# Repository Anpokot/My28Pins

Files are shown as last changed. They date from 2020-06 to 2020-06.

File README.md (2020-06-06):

## My28Pins Project

### My28Pins is an a microcontroller board based on Arduino Uno<br />
The main difference from Uno is an improved layout and selection of 5V or 3.3V operation voltage<br />
This repository contains Altium design files and fabrication output files

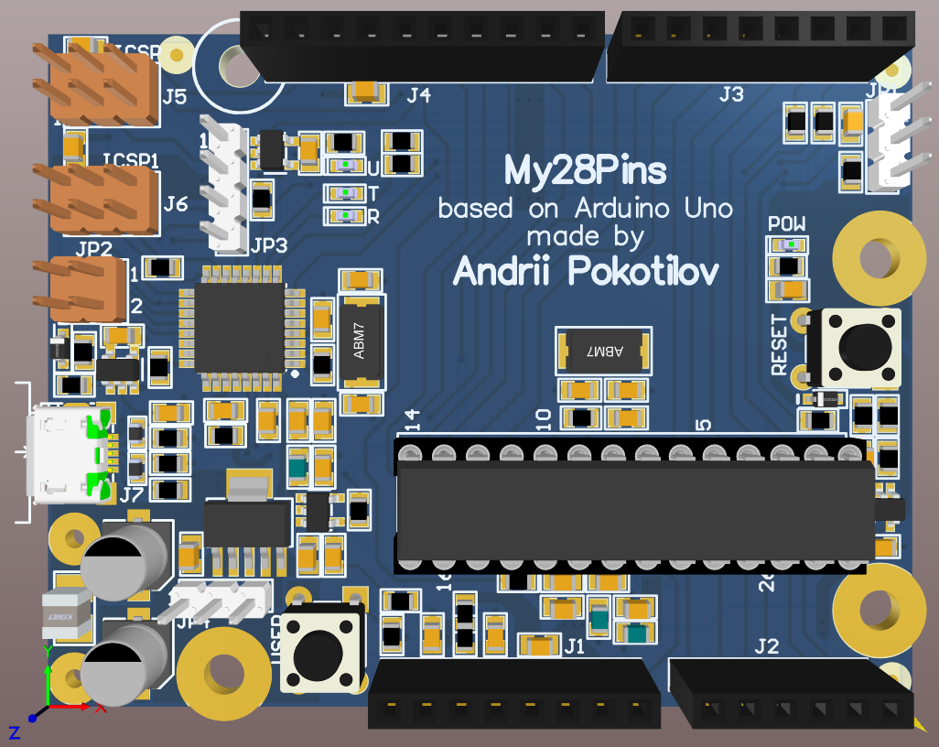
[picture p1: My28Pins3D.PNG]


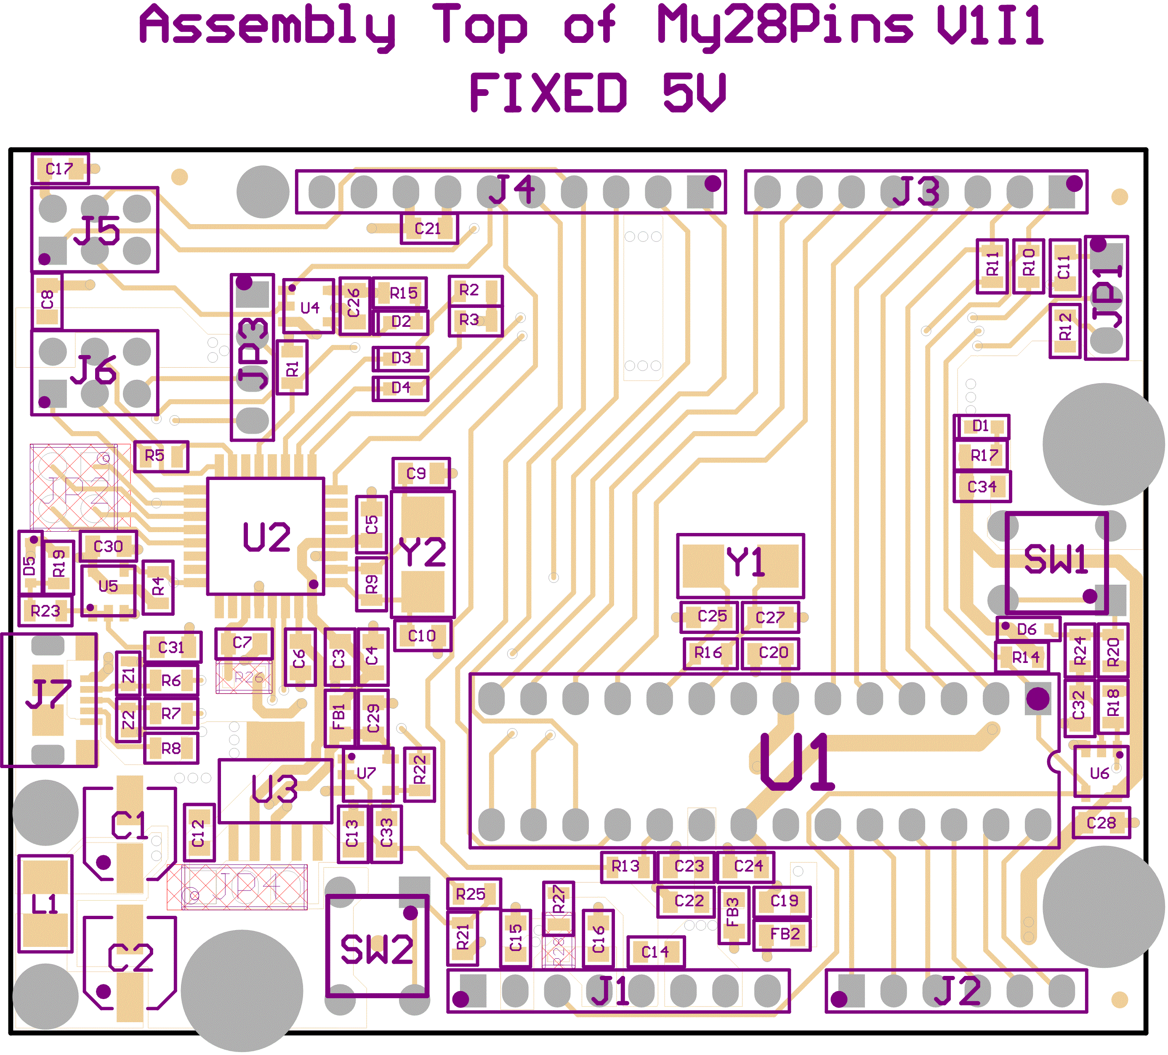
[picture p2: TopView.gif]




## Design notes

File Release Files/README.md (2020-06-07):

### Folder Sructure

Output Job file configured to automaticaly create folder structure

Specify your release folder and template then folow each step:
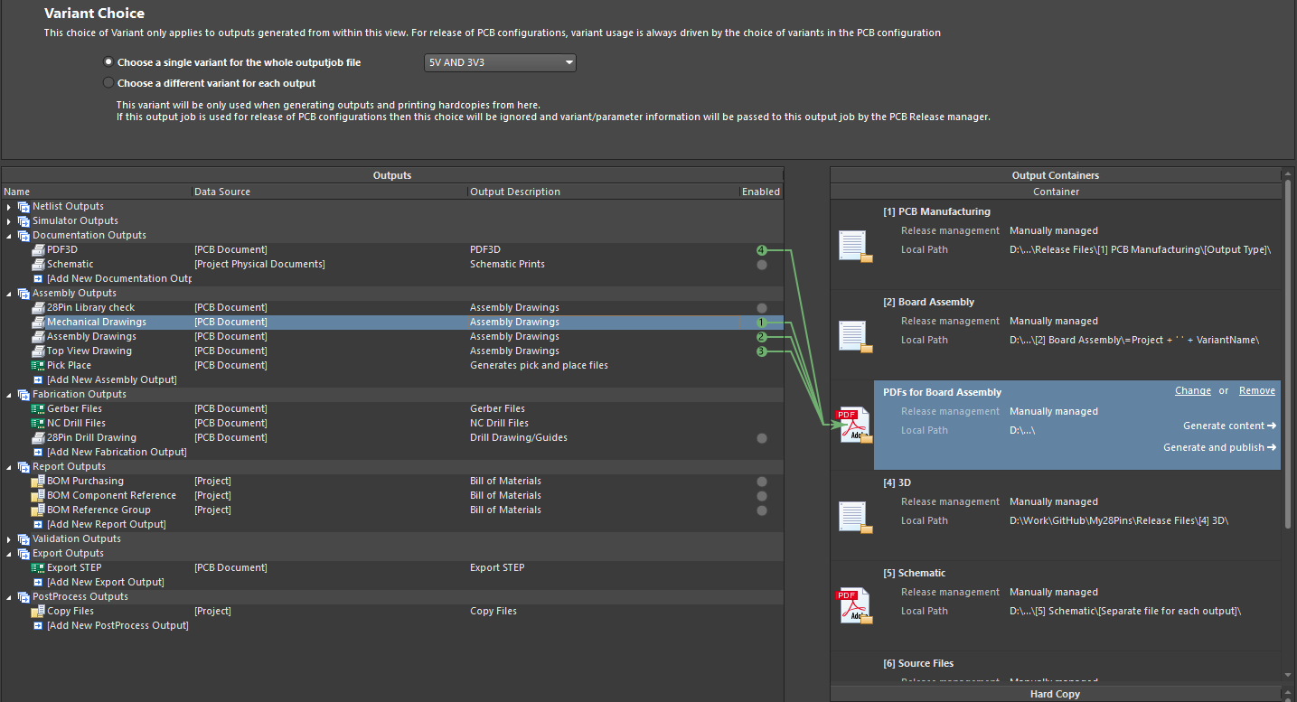
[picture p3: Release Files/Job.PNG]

Each Variant have its own folder

Resulting folder structure should be like this:
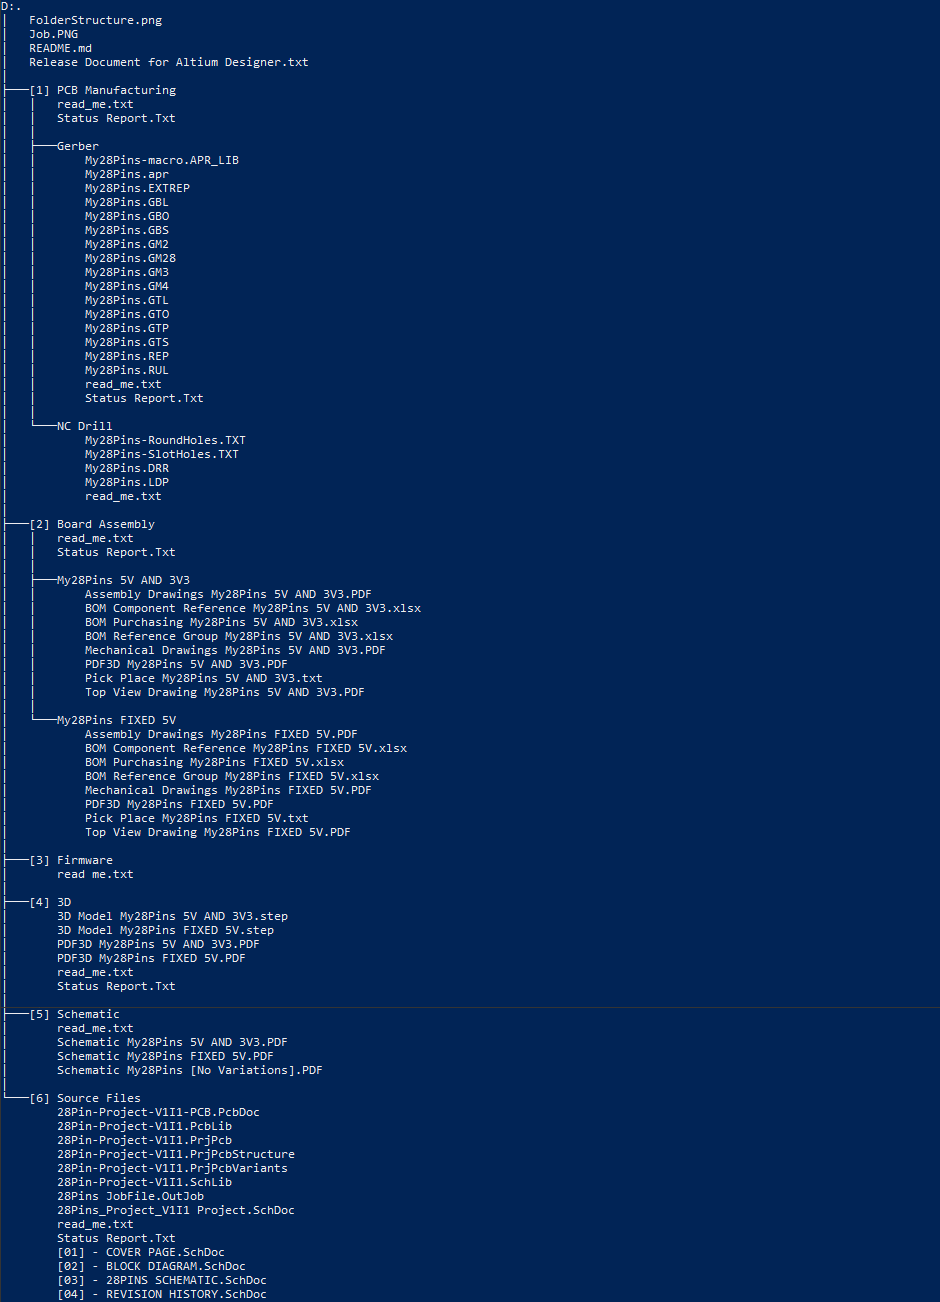
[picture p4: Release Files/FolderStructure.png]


### NOTE: Your variant name must not contain windows prohibited symbols:
`<` `>` `:` `"` `/` `\` `|` `?` `*`

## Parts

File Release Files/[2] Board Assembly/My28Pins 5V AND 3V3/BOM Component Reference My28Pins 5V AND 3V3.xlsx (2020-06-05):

 | Component reference list |  |  | BOM Component Reference
 |  | Source Data From: | 28Pin-Project-V1I1.PrjPcb |  | Contact: |  | Generated by:
 |  | Project: | My28Pins |  |  |  | Andrii Pokotilov
 |  | Variant: | 5V AND 3V3
 | Report Date: | 6/5/2020 | 11:48 AM |  |  |  | https://github.com/Anpokot
 | Print Date: | 2020-06-05 | 11:48:37
# | Designator | Comment | Description | Manufacturer 1 | Manufacturer Part Number 1 | Case/Package | Supplier 1 | Supplier Part Number 1
1 | C1 | 100uF/10V | Cap Aluminum 100uF 10V 20% (5 X 5.4mm) SMD 50mA 1000 hr 85°C T/R | Panasonic | EEE-1AA101WR | Radial | Digi-Key | PCE3867CT-ND
2 | C2 | 100uF/10V | Cap Aluminum 100uF 10V 20% (5 X 5.4mm) SMD 50mA 1000 hr 85°C T/R | Panasonic | EEE-1AA101WR | Radial | Digi-Key | PCE3867CT-ND
3 | C3 | 100n | TDK - C2012X7R1H104K085AA - SMD Multilayer Ceramic Capacitor, 0.1 µF, 50 V, 0805 [2012 Metric], ± 10%, X7R, C Series | TDK | C2012X7R1H104K085AA | 0805 | Digi-Key | 445-7534-1-ND
4 | C4 | 10uF/16V | CERAMIC CAPACITOR, 10UF, 16V, X5R, 20%, 0805, FULL REEL; Product Range:C Series; Capacitance:10 F; Capacitance Tolerance: 20%; Dielectric Characteristic:X5R; Voltage Rating:16V; Ceramic Capacitor Case:0805 [2012 Metric]; MSL:- ;RoHS Compliant: Yes | TDK | C2012X5R1C106M125AC | 0805 | Farnell | 2525134
5 | C5 | 100n | TDK - C2012X7R1H104K085AA - SMD Multilayer Ceramic Capacitor, 0.1 µF, 50 V, 0805 [2012 Metric], ± 10%, X7R, C Series | TDK | C2012X7R1H104K085AA | 0805 | Digi-Key | 445-7534-1-ND
6 | C6 | 100n | TDK - C2012X7R1H104K085AA - SMD Multilayer Ceramic Capacitor, 0.1 µF, 50 V, 0805 [2012 Metric], ± 10%, X7R, C Series | TDK | C2012X7R1H104K085AA | 0805 | Digi-Key | 445-7534-1-ND
7 | C7 | 1uF/25V | TDK - C2012X5R1E105K125AA - SMD Multilayer Ceramic Capacitor, 1 µF, 25 V, 0805 [2012 Metric], ± 10%, X5R, C Series | TDK | C2012X5R1E105K125AA | 0805 | Digi-Key | 445-1419-1-ND
8 | C8 | 100n | TDK - C2012X7R1H104K085AA - SMD Multilayer Ceramic Capacitor, 0.1 µF, 50 V, 0805 [2012 Metric], ± 10%, X7R, C Series | TDK | C2012X7R1H104K085AA | 0805 | Digi-Key | 445-7534-1-ND
9 | C9 | 18p | CAP CER 18PF 50V C0G/NP0 0805 | KEMET | C0805C180J5GACTU | 0805 | Digi-Key | 399-1112-1-ND
10 | C10 | 18p | CAP CER 18PF 50V C0G/NP0 0805 | KEMET | C0805C180J5GACTU | 0805 | Digi-Key | 399-1112-1-ND
11 | C11 | 100n | TDK - C2012X7R1H104K085AA - SMD Multilayer Ceramic Capacitor, 0.1 µF, 50 V, 0805 [2012 Metric], ± 10%, X7R, C Series | TDK | C2012X7R1H104K085AA | 0805 | Digi-Key | 445-7534-1-ND
12 | C12 | 10uF/16V | CERAMIC CAPACITOR, 10UF, 16V, X5R, 20%, 0805, FULL REEL; Product Range:C Series; Capacitance:10 F; Capacitance Tolerance: 20%; Dielectric Characteristic:X5R; Voltage Rating:16V; Ceramic Capacitor Case:0805 [2012 Metric]; MSL:- ;RoHS Compliant: Yes | TDK | C2012X5R1C106M125AC | 0805 | Farnell | 2525134
13 | C13 | 10uF/16V | CERAMIC CAPACITOR, 10UF, 16V, X5R, 20%, 0805, FULL REEL; Product Range:C Series; Capacitance:10 F; Capacitance Tolerance: 20%; Dielectric Characteristic:X5R; Voltage Rating:16V; Ceramic Capacitor Case:0805 [2012 Metric]; MSL:- ;RoHS Compliant: Yes | TDK | C2012X5R1C106M125AC | 0805 | Farnell | 2525134
14 | C14 | 100n | TDK - C2012X7R1H104K085AA - SMD Multilayer Ceramic Capacitor, 0.1 µF, 50 V, 0805 [2012 Metric], ± 10%, X7R, C Series | TDK | C2012X7R1H104K085AA | 0805 | Digi-Key | 445-7534-1-ND
15 | C15 | 100n | TDK - C2012X7R1H104K085AA - SMD Multilayer Ceramic Capacitor, 0.1 µF, 50 V, 0805 [2012 Metric], ± 10%, X7R, C Series | TDK | C2012X7R1H104K085AA | 0805 | Digi-Key | 445-7534-1-ND
16 | C16 | 100n | TDK - C2012X7R1H104K085AA - SMD Multilayer Ceramic Capacitor, 0.1 µF, 50 V, 0805 [2012 Metric], ± 10%, X7R, C Series | TDK | C2012X7R1H104K085AA | 0805 | Digi-Key | 445-7534-1-ND
17 | C17 | 100n | TDK - C2012X7R1H104K085AA - SMD Multilayer Ceramic Capacitor, 0.1 µF, 50 V, 0805 [2012 Metric], ± 10%, X7R, C Series | TDK | C2012X7R1H104K085AA | 0805 | Digi-Key | 445-7534-1-ND
18 | C19 | 10uF/16V | CERAMIC CAPACITOR, 10UF, 16V, X5R, 20%, 0805, FULL REEL; Product Range:C Series; Capacitance:10 F; Capacitance Tolerance: 20%; Dielectric Characteristic:X5R; Voltage Rating:16V; Ceramic Capacitor Case:0805 [2012 Metric]; MSL:- ;RoHS Compliant: Yes | TDK | C2012X5R1C106M125AC | 0805 | Farnell | 2525134
19 | C20 | 100n | TDK - C2012X7R1H104K085AA - SMD Multilayer Ceramic Capacitor, 0.1 µF, 50 V, 0805 [2012 Metric], ± 10%, X7R, C Series | TDK | C2012X7R1H104K085AA | 0805 | Digi-Key | 445-7534-1-ND
20 | C21 | 10uF/16V | CERAMIC CAPACITOR, 10UF, 16V, X5R, 20%, 0805, FULL REEL; Product Range:C Series; Capacitance:10 F; Capacitance Tolerance: 20%; Dielectric Characteristic:X5R; Voltage Rating:16V; Ceramic Capacitor Case:0805 [2012 Metric]; MSL:- ;RoHS Compliant: Yes | TDK | C2012X5R1C106M125AC | 0805 | Farnell | 2525134
21 | C22 | 10uF/16V | CERAMIC CAPACITOR, 10UF, 16V, X5R, 20%, 0805, FULL REEL; Product Range:C Series; Capacitance:10 F; Capacitance Tolerance: 20%; Dielectric Characteristic:X5R; Voltage Rating:16V; Ceramic Capacitor Case:0805 [2012 Metric]; MSL:- ;RoHS Compliant: Yes | TDK | C2012X5R1C106M125AC | 0805 | Farnell | 2525134
22 | C23 | 100n | TDK - C2012X7R1H104K085AA - SMD Multilayer Ceramic Capacitor, 0.1 µF, 50 V, 0805 [2012 Metric], ± 10%, X7R, C Series | TDK | C2012X7R1H104K085AA | 0805 | Digi-Key | 445-7534-1-ND
23 | C24 | 100n | TDK - C2012X7R1H104K085AA - SMD Multilayer Ceramic Capacitor, 0.1 µF, 50 V, 0805 [2012 Metric], ± 10%, X7R, C Series | TDK | C2012X7R1H104K085AA | 0805 | Digi-Key | 445-7534-1-ND
24 | C25 | 18p | CAP CER 18PF 50V C0G/NP0 0805 | KEMET | C0805C180J5GACTU | 0805 | Digi-Key | 399-1112-1-ND
25 | C26 | 100n | TDK - C2012X7R1H104K085AA - SMD Multilayer Ceramic Capacitor, 0.1 µF, 50 V, 0805 [2012 Metric], ± 10%, X7R, C Series | TDK | C2012X7R1H104K085AA | 0805 | Digi-Key | 445-7534-1-ND
26 | C27 | 18p | CAP CER 18PF 50V C0G/NP0 0805 | KEMET | C0805C180J5GACTU | 0805 | Digi-Key | 399-1112-1-ND
27 | C28 | 100n | TDK - C2012X7R1H104K085AA - SMD Multilayer Ceramic Capacitor, 0.1 µF, 50 V, 0805 [2012 Metric], ± 10%, X7R, C Series | TDK | C2012X7R1H104K085AA | 0805 | Digi-Key | 445-7534-1-ND
28 | C29 | 100n | TDK - C2012X7R1H104K085AA - SMD Multilayer Ceramic Capacitor, 0.1 µF, 50 V, 0805 [2012 Metric], ± 10%, X7R, C Series | TDK | C2012X7R1H104K085AA | 0805 | Digi-Key | 445-7534-1-ND
29 | C30 | 100n | TDK - C2012X7R1H104K085AA - SMD Multilayer Ceramic Capacitor, 0.1 µF, 50 V, 0805 [2012 Metric], ± 10%, X7R, C Series | TDK | C2012X7R1H104K085AA | 0805 | Digi-Key | 445-7534-1-ND
30 | C31 | 100n | TDK - C2012X7R1H104K085AA - SMD Multilayer Ceramic Capacitor, 0.1 µF, 50 V, 0805 [2012 Metric], ± 10%, X7R, C Series | TDK | C2012X7R1H104K085AA | 0805 | Digi-Key | 445-7534-1-ND
31 | C32 | 100n | TDK - C2012X7R1H104K085AA - SMD Multilayer Ceramic Capacitor, 0.1 µF, 50 V, 0805 [2012 Metric], ± 10%, X7R, C Series | TDK | C2012X7R1H104K085AA | 0805 | Digi-Key | 445-7534-1-ND
32 | C33 | 100n | TDK - C2012X7R1H104K085AA - SMD Multilayer Ceramic Capacitor, 0.1 µF, 50 V, 0805 [2012 Metric], ± 10%, X7R, C Series | TDK | C2012X7R1H104K085AA | 0805 | Digi-Key | 445-7534-1-ND
33 | C34 | 10uF/16V | CERAMIC CAPACITOR, 10UF, 16V, X5R, 20%, 0805, FULL REEL; Product Range:C Series; Capacitance:10 F; Capacitance Tolerance: 20%; Dielectric Characteristic:X5R; Voltage Rating:16V; Ceramic Capacitor Case:0805 [2012 Metric]; MSL:- ;RoHS Compliant: Yes | TDK | C2012X5R1C106M125AC | 0805 | Farnell | 2525134
34 | D1 | GREEN | LED Uni-Color Green 572nm 2-Pin Chip 0603(1608Metric) T/R | Osram Opto | LGL29K-G2J1-24-Z | 0603 | Digi-Key | 475-2709-1-ND
35 | D2 | ORANGE | OSRAM - LO L29K-H2K1-24-Z - SMARTLED 0603 ORANGE | Osram Opto | LOL29K-H2K1-24-Z | 0603 | Digi-Key | 475-2740-1-ND
36 | D3 | ORANGE | OSRAM - LO L29K-H2K1-24-Z - SMARTLED 0603 ORANGE | Osram Opto | LOL29K-H2K1-24-Z | 0603 | Digi-Key | 475-2740-1-ND
37 | D4 | ORANGE | OSRAM - LO L29K-H2K1-24-Z - SMARTLED 0603 ORANGE | Osram Opto | LOL29K-H2K1-24-Z | 0603 | Digi-Key | 475-2740-1-ND
38 | D5 | BAT54HT1G | Small Signal Schottky Diode, Single, 30 V, 200 mA, 800 mV, 600 mA, 150 C ;RoHS Compliant: Yes | ON Semiconductor / Fairchild | BAT54HT1G |  | Digi-Key | BAT54HT1GOSCT-ND
39 | D6 | BAT54HT1G | Small Signal Schottky Diode, Single, 30 V, 200 mA, 800 mV, 600 mA, 150 C ;RoHS Compliant: Yes | ON Semiconductor / Fairchild | BAT54HT1G |  | Digi-Key | BAT54HT1GOSCT-ND
40 | FB1 | MPZ2012S601AT000 | FERRITE BEAD 600 OHM 0805 1LN | TDK | MPZ2012S601AT000 | 0805 | Digi-Key | 445-2206-1-ND
41 | FB2 | MPZ2012S601AT000 | FERRITE BEAD 600 OHM 0805 1LN | TDK | MPZ2012S601AT000 | 0805 | Digi-Key | 445-2206-1-ND
42 | FB3 | MPZ2012S601AT000 | FERRITE BEAD 600 OHM 0805 1LN | TDK | MPZ2012S601AT000 | 0805 | Digi-Key | 445-2206-1-ND
43 | J1 | Hdr 1x8 | 8POS, 2.54MM, 1ROW | Harwin | M20-7910842R |  | Digi-Key | 952-3200-1-ND
44 | J2 | Hdr 1x6 | 6Pin 2.54mm Conn Socket Strip SKT 6 POS 2.54mm Solder ST Thru-Hole Tube | Harwin | M20-7820642 | SIL | Digi-Key | 952-1808-ND
45 | J3 | Hdr 1x8 | 8POS, 2.54MM, 1ROW | Harwin | M20-7910842R |  | Digi-Key | 952-3200-1-ND
46 | J4 | Hdr 1x10 | 10Pin, 2.54 mm, Tin Plated Contacts | Harwin | M20-7821046 | SIL | Digi-Key | 952-1847-ND
47 | J5 | HDR 2x3 | CONN HEADER 6POS .100 STR 30AU | Amphenol ICC / FCI | 67997-106HLF |  | Digi-Key | 609-3393-ND
48 | J6 | HDR 2x3 | CONN HEADER 6POS .100 STR 30AU | Amphenol ICC / FCI | 67997-106HLF |  | Digi-Key | 609-3393-ND
49 | J7 | 10118193-0001LF | CONN USB MICRO B RECPT SMT R/A | Amphenol ICC | 10118193-0001LF |  | Digi-Key | 609-4616-1-ND
50 | JP1 | HDR 1x3 | Conn Unshrouded Header HDR 3 POS 2.54mm Solder ST Thru-Hole Bulk | Amphenol ICC | 68000-103HLF |  | Digi-Key | 609-3461-ND
51 | JP3 | HDR 1x4 | CONN HEADER VERT 4POS 2.54MM | Amphenol FCI | 68001-204HLF |  | Digi-Key | 609-3402-ND
52 | JP4 | HDR 1x3 | Conn Unshrouded Header HDR 3 POS 2.54mm Solder ST Thru-Hole Bulk | Amphenol ICC | 68000-103HLF |  | Digi-Key | 609-3461-ND
53 | L1 | 2u2/2A | FIXED IND 2.2UH 2A 80 MOHM SMD | KEMET | L1210R2R2MDWIT | 1210 | Digi-Key | 399-9598-1-ND
54 | LINK1 | LINK | CONN JUMPER SHORTING .100" GOLD | Sullins | QPC02SXGN-RC | 100 | Digi-Key | S9337-ND
55 | LINK2 | LINK | CONN JUMPER SHORTING .100" GOLD | Sullins | QPC02SXGN-RC | 100 | Digi-Key | S9337-ND
56 | LINK3 | LINK | CONN JUMPER SHORTING .100" GOLD | Sullins | QPC02SXGN-RC | 100 | Digi-Key | S9337-ND
57 | R1 | 100K | YAGEO RC0805FR-07100KL RES, THICK FILM, 100K, 1%, 0.125W, 0805, REEL | Yageo | RC0805FR-07100KL | 0805 | Digi-Key | 311-100KCRDKR-ND
58 | R2 | 560R | Surface Mount Thick Film Resistor, RC Series, 560 ohm, 125 mW, - 1%, 150 V, 0805 [2012 Metric] | Yageo | RC0805FR-07560RL | 0805 | Digi-Key | 311-560CRCT-ND
59 | R3 | 560R | Surface Mount Thick Film Resistor, RC Series, 560 ohm, 125 mW, - 1%, 150 V, 0805 [2012 Metric] | Yageo | RC0805FR-07560RL | 0805 | Digi-Key | 311-560CRCT-ND
60 | R4 | 10K | RES SMD 10K OHM 1% 1/8W 0805 | Yageo | RC0805FR-0710KL | 0805 | Digi-Key | 311-10.0KCRDKR-ND
61 | R5 | 22R | RES SMD 22 OHM 1% 1/8W 0805 | Yageo | RC0805FR-0722RL | 0805 | Digi-Key | 311-22.0CRCT-ND
62 | R6 | 22R | RES SMD 22 OHM 1% 1/8W 0805 | Yageo | RC0805FR-0722RL | 0805 | Digi-Key | 311-22.0CRCT-ND
63 | R7 | 22R | RES SMD 22 OHM 1% 1/8W 0805 | Yageo | RC0805FR-0722RL | 0805 | Digi-Key | 311-22.0CRCT-ND
64 | R8 | 0R | Surface Mount Thick Film Resistor, RC Series, 125 mW, - 5%, 150 V, 0805 [2012 Metric] | Yageo | RC0805JR-070RL | 0805 | Digi-Key | 311-0.0ARCT-ND
65 | R9 | 1M | RES SMD 1M OHM 1% 1/8W 0805 | Yageo | RC0805FR-071ML | 0805 | Arrow | RC0805FR-071ML
66 | R10 | 1K | RESISTOR, 0805 1K 1%, FULL REEL; Product Range:YAGEO - RC Series; Resistance:1kohm; Power Rating:125mW; Resistance Tolerance:± 1%; Resistor Case Style:0805 [2012 Metric]; Resistor Element Material:Thick Film; Temperature Coefficient:± 250ppm/°C; Voltage Rating:150V; Packaging:Tape & Reel; MSL:-; SVHC:No SVHC (16-Dec-2013); External Depth:0.55mm; External Length / Height:2mm; External Width:1.25mm; No. of Pins:2; Operating Temperature Max:155°C; Operating Temperature Min:-55°C; Operating Temperature Range:-55°C to +155°C; Reel Quantity:5000; Resistor Mounting:SMD; Series:RC12H; Temperature Coef | Yageo Phycomp | RC0805FR-071KL | 0805 | Digi-Key | 311-1.00KCRDKR-ND
67 | R11 | 1K | RESISTOR, 0805 1K 1%, FULL REEL; Product Range:YAGEO - RC Series; Resistance:1kohm; Power Rating:125mW; Resistance Tolerance:± 1%; Resistor Case Style:0805 [2012 Metric]; Resistor Element Material:Thick Film; Temperature Coefficient:± 250ppm/°C; Voltage Rating:150V; Packaging:Tape & Reel; MSL:-; SVHC:No SVHC (16-Dec-2013); External Depth:0.55mm; External Length / Height:2mm; External Width:1.25mm; No. of Pins:2; Operating Temperature Max:155°C; Operating Temperature Min:-55°C; Operating Temperature Range:-55°C to +155°C; Reel Quantity:5000; Resistor Mounting:SMD; Series:RC12H; Temperature Coef | Yageo Phycomp | RC0805FR-071KL | 0805 | Digi-Key | 311-1.00KCRDKR-ND
68 | R12 | 1K | RESISTOR, 0805 1K 1%, FULL REEL; Product Range:YAGEO - RC Series; Resistance:1kohm; Power Rating:125mW; Resistance Tolerance:± 1%; Resistor Case Style:0805 [2012 Metric]; Resistor Element Material:Thick Film; Temperature Coefficient:± 250ppm/°C; Voltage Rating:150V; Packaging:Tape & Reel; MSL:-; SVHC:No SVHC (16-Dec-2013); External Depth:0.55mm; External Length / Height:2mm; External Width:1.25mm; No. of Pins:2; Operating Temperature Max:155°C; Operating Temperature Min:-55°C; Operating Temperature Range:-55°C to +155°C; Reel Quantity:5000; Resistor Mounting:SMD; Series:RC12H; Temperature Coef | Yageo Phycomp | RC0805FR-071KL | 0805 | Digi-Key | 311-1.00KCRDKR-ND
69 | R13 | 22R | RES SMD 22 OHM 1% 1/8W 0805 | Yageo | RC0805FR-0722RL | 0805 | Digi-Key | 311-22.0CRCT-ND
70 | R14 | 10K | RES SMD 10K OHM 1% 1/8W 0805 | Yageo | RC0805FR-0710KL | 0805 | Digi-Key | 311-10.0KCRDKR-ND
71 | R15 | 560R | Surface Mount Thick Film Resistor, RC Series, 560 ohm, 125 mW, - 1%, 150 V, 0805 [2012 Metric] | Yageo | RC0805FR-07560RL | 0805 | Digi-Key | 311-560CRCT-ND
72 | R16 | 1M | RES SMD 1M OHM 1% 1/8W 0805 | Yageo | RC0805FR-071ML | 0805 | Arrow | RC0805FR-071ML
73 | R17 | 560R | Surface Mount Thick Film Resistor, RC Series, 560 ohm, 125 mW, - 1%, 150 V, 0805 [2012 Metric] | Yageo | RC0805FR-07560RL | 0805 | Digi-Key | 311-560CRCT-ND
74 | R18 | 10K | RES SMD 10K OHM 1% 1/8W 0805 | Yageo | RC0805FR-0710KL | 0805 | Digi-Key | 311-10.0KCRDKR-ND
75 | R19 | 10K | RES SMD 10K OHM 1% 1/8W 0805 | Yageo | RC0805FR-0710KL | 0805 | Digi-Key | 311-10.0KCRDKR-ND
76 | R20 | 10K | RES SMD 10K OHM 1% 1/8W 0805 | Yageo | RC0805FR-0710KL | 0805 | Digi-Key | 311-10.0KCRDKR-ND
77 | R21 | 10K | RES SMD 10K OHM 1% 1/8W 0805 | Yageo | RC0805FR-0710KL | 0805 | Digi-Key | 311-10.0KCRDKR-ND
78 | R22 | 560R | Surface Mount Thick Film Resistor, RC Series, 560 ohm, 125 mW, - 1%, 150 V, 0805 [2012 Metric] | Yageo | RC0805FR-07560RL | 0805 | Digi-Key | 311-560CRCT-ND
79 | R23 | 22R | RES SMD 22 OHM 1% 1/8W 0805 | Yageo | RC0805FR-0722RL | 0805 | Digi-Key | 311-22.0CRCT-ND
80 | R24 | 22R | RES SMD 22 OHM 1% 1/8W 0805 | Yageo | RC0805FR-0722RL | 0805 | Digi-Key | 311-22.0CRCT-ND
81 | R25 | 22R | RES SMD 22 OHM 1% 1/8W 0805 | Yageo | RC0805FR-0722RL | 0805 | Digi-Key | 311-22.0CRCT-ND
82 | SOCKET FOR U1 | 28-Dip Socket | CONN IC DIP SOCKET 28POS TIN | 3M | 7010501790 |  | Digi-Key | 3M5480-ND
83 | SW1 | 1825910-6 | SWITCH TACTILE SPST-NO 0.05A 24V | TE Connectivity | FSM4JH |  | Digi-Key | 450-1650-ND
84 | SW2 | 1825910-6 | SWITCH TACTILE SPST-NO 0.05A 24V | TE Connectivity | FSM4JH |  | Digi-Key | 450-1650-ND
85 | U1 | ATMEGA328P-PU | ATMEGA328P-PU; 8 bit Microcontroller AVR 20MHz 1; 32kb Flash; 2kb RAM; I2C SPI 2 | Microchip / Atmel | ATMEGA328P-PU | PDIP | Digi-Key | ATMEGA328P-PU-ND
86 | U2 | ATMEGA16U2-AU-ND | MICROCHIP - ATMEGA16U2-AU - MCU, 8BIT, MEGAAVR, 16MHZ, TQFP-32 | Microchip | ATMEGA16U2-AU | A | Digi-Key | ATMEGA16U2-AU-ND
87 | U3 | TL1963A-33DCQR | IC REG LINEAR 3.3V 1.5A SOT223-6 | Texas Instruments | TL1963A-33DCQR | SOT-223 | Digi-Key | 296-24534-1-ND
88 | U4 | SN74AHC1G09DBVR | TEXAS INSTRUMENTS - SN74AHC1G09DBVR - AND Gate, 74AHC1G09, 2 Input, 2 V to 5.5 V, SOT-23-5 | Texas Instruments | SN74AHC1G09DBVR | SOT-23 | Digi-Key | 296-29202-1-ND
89 | U5 | SN74AHC1G09DBVR | TEXAS INSTRUMENTS - SN74AHC1G09DBVR - AND Gate, 74AHC1G09, 2 Input, 2 V to 5.5 V, SOT-23-5 | Texas Instruments | SN74AHC1G09DBVR | SOT-23 | Digi-Key | 296-29202-1-ND
90 | U6 | SN74AHC1G09DBVR | TEXAS INSTRUMENTS - SN74AHC1G09DBVR - AND Gate, 74AHC1G09, 2 Input, 2 V to 5.5 V, SOT-23-5 | Texas Instruments | SN74AHC1G09DBVR | SOT-23 | Digi-Key | 296-29202-1-ND
91 | U7 | SN74AHC1G09DBVR | TEXAS INSTRUMENTS - SN74AHC1G09DBVR - AND Gate, 74AHC1G09, 2 Input, 2 V to 5.5 V, SOT-23-5 | Texas Instruments | SN74AHC1G09DBVR | SOT-23 | Digi-Key | 296-29202-1-ND
92 | Y1 | 8 MHz | ABRACON - ABM7-8.000MHZ-D2Y-T - Crystal, Miniature, 8 MHz, SMD, 6mm x 3.5mm, 30 ppm, 18 pF, 20 ppm, ABM7 Series | Abracon | ABM7-8.000MHZ-D2Y-T | CSMD | Digi-Key | 535-9831-1-ND
93 | Y2 | 10 MHz | CRYSTAL 10.0000MHZ 18PF SMD | Abracon | ABM7-10.000MHZ-D2Y-T | SMD/SMT | Digi-Key | 535-9833-1-ND
94 | Z1 | CG0603MLC-05E | VARISTOR 0603 | Bourns | CG0603MLC-05E | 0603 | Digi-Key | CG0603MLC-05ECT-ND
95 | Z2 | CG0603MLC-05E | VARISTOR 0603 | Bourns | CG0603MLC-05E | 0603 | Digi-Key | CG0603MLC-05ECT-ND
Approved |  |  |  | Notes

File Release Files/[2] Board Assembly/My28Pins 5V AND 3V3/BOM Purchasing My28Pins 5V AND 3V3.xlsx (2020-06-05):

 | Component list |  |  | BOM Purchasing
 | Source Data From: | 28Pin-Project-V1I1.PrjPcb |  |  |  |  |  |  | Generated by:
 | Project: | My28Pins |  |  |  |  |  |  | Andrii Pokotilov
 | Variant: | 5V AND 3V3
 | Report Date: | 6/5/2020 | 11:47 AM |  |  |  |  |  | https://github.com/Anpokot
 | Print Date: | 2020-06-05 | 11:48:01
# | Category | Manufacturer 1 | Manufacturer Part Number 1 | Case/Package | Description | Quantity | Supplier 1 | Supplier Part Number 1 | Supplier Order Qty 1 | Supplier Stock 1 | Supplier Unit Price 1 | Supplier Subtotal 1 | Supplier Currency 1
1 | Aluminum Electrolytic Capacitors | Panasonic | EEE-1AA101WR | Radial | Cap Aluminum 100uF 10V 20% (5 X 5.4mm) SMD 50mA 1000 hr 85°C T/R | 2 | Digi-Key | PCE3867CT-ND | 2000 | 60146 | 0.09964 | 199.28 | USD
2 | Ceramic Capacitors | KEMET | C0805C180J5GACTU | 0805 | CAP CER 18PF 50V C0G/NP0 0805 | 4 | Digi-Key | 399-1112-1-ND | 4000 | 169363 | 0.02716 | 108.64 | USD
3 | Ceramic Capacitors | TDK | C2012X5R1C106M125AC | 0805 | CERAMIC CAPACITOR, 10UF, 16V, X5R, 20%, 0805, FULL REEL; Product Range:C Series; Capacitance:10 F; Capacitance Tolerance: 20%; Dielectric Characteristic:X5R; Voltage Rating:16V; Ceramic Capacitor Case:0805 [2012 Metric]; MSL:- ;RoHS Compliant: Yes | 7 | Farnell | 2525134 | 7000 | 0 | 0.0488 | 341.6 | GBP
4 | Ceramic Capacitors | TDK | C2012X5R1E105K125AA | 0805 | TDK - C2012X5R1E105K125AA - SMD Multilayer Ceramic Capacitor, 1 µF, 25 V, 0805 [2012 Metric], ± 10%, X5R, C Series | 1 | Digi-Key | 445-1419-1-ND | 1000 | 29808 | 0.05586 | 55.86 | USD
5 | Ceramic Capacitors | TDK | C2012X7R1H104K085AA | 0805 | TDK - C2012X7R1H104K085AA - SMD Multilayer Ceramic Capacitor, 0.1 µF, 50 V, 0805 [2012 Metric], ± 10%, X7R, C Series | 19 | Digi-Key | 445-7534-1-ND | 19000 | 241464 | 0.03258 | 619.02 | USD
6 | Chip SMD Resistors | Yageo | RC0805FR-071ML | 0805 | RES SMD 1M OHM 1% 1/8W 0805 | 2 | Arrow | RC0805FR-071ML |  | 0
7 | Chip SMD Resistors | Yageo | RC0805FR-0710KL | 0805 | RES SMD 10K OHM 1% 1/8W 0805 | 6 | Digi-Key | 311-10.0KCRDKR-ND | 6000 | 22153735 | 0.00635 | 38.1 | USD
8 | Chip SMD Resistors | Yageo | RC0805FR-0722RL | 0805 | RES SMD 22 OHM 1% 1/8W 0805 | 7 | Digi-Key | 311-22.0CRCT-ND | 7000 | 528696 | 0.00635 | 44.45 | USD
9 | Chip SMD Resistors | Yageo Phycomp | RC0805FR-071KL | 0805 | RESISTOR, 0805 1K 1%, FULL REEL; Product Range:YAGEO - RC Series; Resistance:1kohm; Power Rating:125mW; Resistance Tolerance:± 1%; Resistor Case Style:0805 [2012 Metric]; Resistor Element Material:Thick Film; Temperature Coefficient:± 250ppm/°C; Voltage Rating:150V; Packaging:Tape & Reel; MSL:-; SVHC:No SVHC (16-Dec-2013); External Depth:0.55mm; External Length / Height:2mm; External Width:1.25mm; No. of Pins:2; Operating Temperature Max:155°C; Operating Temperature Min:-55°C; Operating Temperature Range:-55°C to +155°C; Reel Quantity:5000; Resistor Mounting:SMD; Series:RC12H; Temperature Coef | 3 | Digi-Key | 311-1.00KCRDKR-ND | 3000 | 19687711 | 0.00635 | 19.05 | USD
10 | Chip SMD Resistors | Yageo | RC0805JR-070RL | 0805 | Surface Mount Thick Film Resistor, RC Series, 125 mW, - 5%, 150 V, 0805 [2012 Metric] | 1 | Digi-Key | 311-0.0ARCT-ND | 1000 | 7980293 | 0.00631 | 6.31 | USD
11 | Chip SMD Resistors | Yageo | RC0805FR-07560RL | 0805 | Surface Mount Thick Film Resistor, RC Series, 560 ohm, 125 mW, - 1%, 150 V, 0805 [2012 Metric] | 5 | Digi-Key | 311-560CRCT-ND | 5000 | 203177 | 0.00635 | 31.75 | USD
12 | Chip SMD Resistors | Yageo | RC0805FR-07100KL | 0805 | YAGEO RC0805FR-07100KL RES, THICK FILM, 100K, 1%, 0.125W, 0805, REEL | 1 | Digi-Key | 311-100KCRDKR-ND | 1000 | 4686552 | 0.00731 | 7.31 | USD
13 | Connectors | Harwin | M20-7910842R |  | 8POS, 2.54MM, 1ROW | 2 | Digi-Key | 952-3200-1-ND | 2000 | 1720 | 0.80388 | 1607.76 | USD
14 | Connectors | 3M | 7010501790 |  | CONN IC DIP SOCKET 28POS TIN | 1 | Digi-Key | 3M5480-ND | 1000 | 4763 | 0.43504 | 435.04 | USD
15 | Connectors | Sullins | QPC02SXGN-RC | 100 | CONN JUMPER SHORTING .100" GOLD | 3 | Digi-Key | S9337-ND | 3000 | 389812 | 0.02394 | 71.82 | USD
16 | Crystals | Abracon | ABM7-8.000MHZ-D2Y-T | CSMD | ABRACON - ABM7-8.000MHZ-D2Y-T - Crystal, Miniature, 8 MHz, SMD, 6mm x 3.5mm, 30 ppm, 18 pF, 20 ppm, ABM7 Series | 1 | Digi-Key | 535-9831-1-ND | 1000 | 77337 | 0.693 | 693 | USD
17 | Crystals | Abracon | ABM7-10.000MHZ-D2Y-T | SMD/SMT | CRYSTAL 10.0000MHZ 18PF SMD | 1 | Digi-Key | 535-9833-1-ND | 1000 | 36040 | 0.693 | 693 | USD
18 | Ferrite Beads and Chips | TDK | MPZ2012S601AT000 | 0805 | FERRITE BEAD 600 OHM 0805 1LN | 3 | Digi-Key | 445-2206-1-ND | 3000 | 224816 | 0.0302 | 90.6 | USD
19 | Fixed Inductors | KEMET | L1210R2R2MDWIT | 1210 | FIXED IND 2.2UH 2A 80 MOHM SMD | 1 | Digi-Key | 399-9598-1-ND | 1000 | 660 | 0.28738 | 287.38 | USD
20 | Headers and Wire Housings | Harwin | M20-7820642 | SIL | 6Pin 2.54mm Conn Socket Strip SKT 6 POS 2.54mm Solder ST Thru-Hole Tube | 1 | Digi-Key | 952-1808-ND | 1000 | 1093 | 0.5456 | 545.6 | USD
21 | Headers and Wire Housings | Harwin | M20-7821046 | SIL | 10Pin, 2.54 mm, Tin Plated Contacts | 1 | Digi-Key | 952-1847-ND | 1000 | 431 | 0.704 | 704 | USD
22 | Headers and Wire Housings | Amphenol ICC / FCI | 67997-106HLF |  | CONN HEADER 6POS .100 STR 30AU | 2 | Digi-Key | 609-3393-ND | 2000 | 1665 | 0.98835 | 1976.7 | USD
23 | Headers and Wire Housings | Amphenol FCI | 68001-204HLF |  | CONN HEADER VERT 4POS 2.54MM | 1 | Digi-Key | 609-3402-ND | 1000 | 3614 | 0.17868 | 178.68 | USD
24 | Headers and Wire Housings | Amphenol ICC | 68000-103HLF |  | Conn Unshrouded Header HDR 3 POS 2.54mm Solder ST Thru-Hole Bulk | 2 | Digi-Key | 609-3461-ND | 2000 | 15419 | 0.1393 | 278.6 | USD
25 | Logic Gates | Texas Instruments | SN74AHC1G09DBVR | SOT-23 | TEXAS INSTRUMENTS - SN74AHC1G09DBVR - AND Gate, 74AHC1G09, 2 Input, 2 V to 5.5 V, SOT-23-5 | 4 | Digi-Key | 296-29202-1-ND | 4000 | 27709 | 0.069 | 276 | USD
26 | Microcontrollers | Microchip / Atmel | ATMEGA328P-PU | PDIP | ATMEGA328P-PU; 8 bit Microcontroller AVR 20MHz 1; 32kb Flash; 2kb RAM; I2C SPI 2 | 1 | Digi-Key | ATMEGA328P-PU-ND | 1000 | 6233 | 1.73 | 1730 | USD
27 | Microcontrollers | Microchip | ATMEGA16U2-AU | A | MICROCHIP - ATMEGA16U2-AU - MCU, 8BIT, MEGAAVR, 16MHZ, TQFP-32 | 1 | Digi-Key | ATMEGA16U2-AU-ND | 1000 | 3462 | 2.04 | 2040 | USD
28 | Pushbutton Switches | TE Connectivity | FSM4JH |  | SWITCH TACTILE SPST-NO 0.05A 24V | 2 | Digi-Key | 450-1650-ND | 2000 | 25452 | 0.06265 | 125.3 | USD
29 | Schottky Diodes | ON Semiconductor / Fairchild | BAT54HT1G |  | Small Signal Schottky Diode, Single, 30 V, 200 mA, 800 mV, 600 mA, 150 C ;RoHS Compliant: Yes | 2 | Digi-Key | BAT54HT1GOSCT-ND | 2000 | 328630 | 0.0414 | 82.8 | USD
30 | Uncategorized | Osram Opto | LGL29K-G2J1-24-Z | 0603 | LED Uni-Color Green 572nm 2-Pin Chip 0603(1608Metric) T/R | 1 | Digi-Key | 475-2709-1-ND | 1000 | 120445 | 0.11153 | 111.53 | USD
31 | Uncategorized | Osram Opto | LOL29K-H2K1-24-Z | 0603 | OSRAM - LO L29K-H2K1-24-Z - SMARTLED 0603 ORANGE | 3 | Digi-Key | 475-2740-1-ND | 3000 | 2134 | 0.1012 | 303.6 | USD
32 | USB Connectors | Amphenol ICC | 10118193-0001LF |  | CONN USB MICRO B RECPT SMT R/A | 1 | Digi-Key | 609-4616-1-ND | 1000 | 147829 | 0.27016 | 270.16 | USD
33 | Varistors | Bourns | CG0603MLC-05E | 0603 | VARISTOR 0603 | 2 | Digi-Key | CG0603MLC-05ECT-ND | 2000 | 11272 | 0.10712 | 214.24 | USD
34 | Voltage Regulators - Linear | Texas Instruments | TL1963A-33DCQR | SOT-223 | IC REG LINEAR 3.3V 1.5A SOT223-6 | 1 | Digi-Key | 296-24534-1-ND | 1000 | 3415 | 1.4 | 1404.48 | USD
 |  |  |  |  |  | 95 |  |  | 93000 |  |  | 15591.66
Approved |  |  |  | Notes
 |  |  |  |  |  | 1000 | pcs: | Total |  | 15591.66 |  | USD
 |  |  |  |  |  |  |  | Price for 1pcs |  | 15.59 |  | USD

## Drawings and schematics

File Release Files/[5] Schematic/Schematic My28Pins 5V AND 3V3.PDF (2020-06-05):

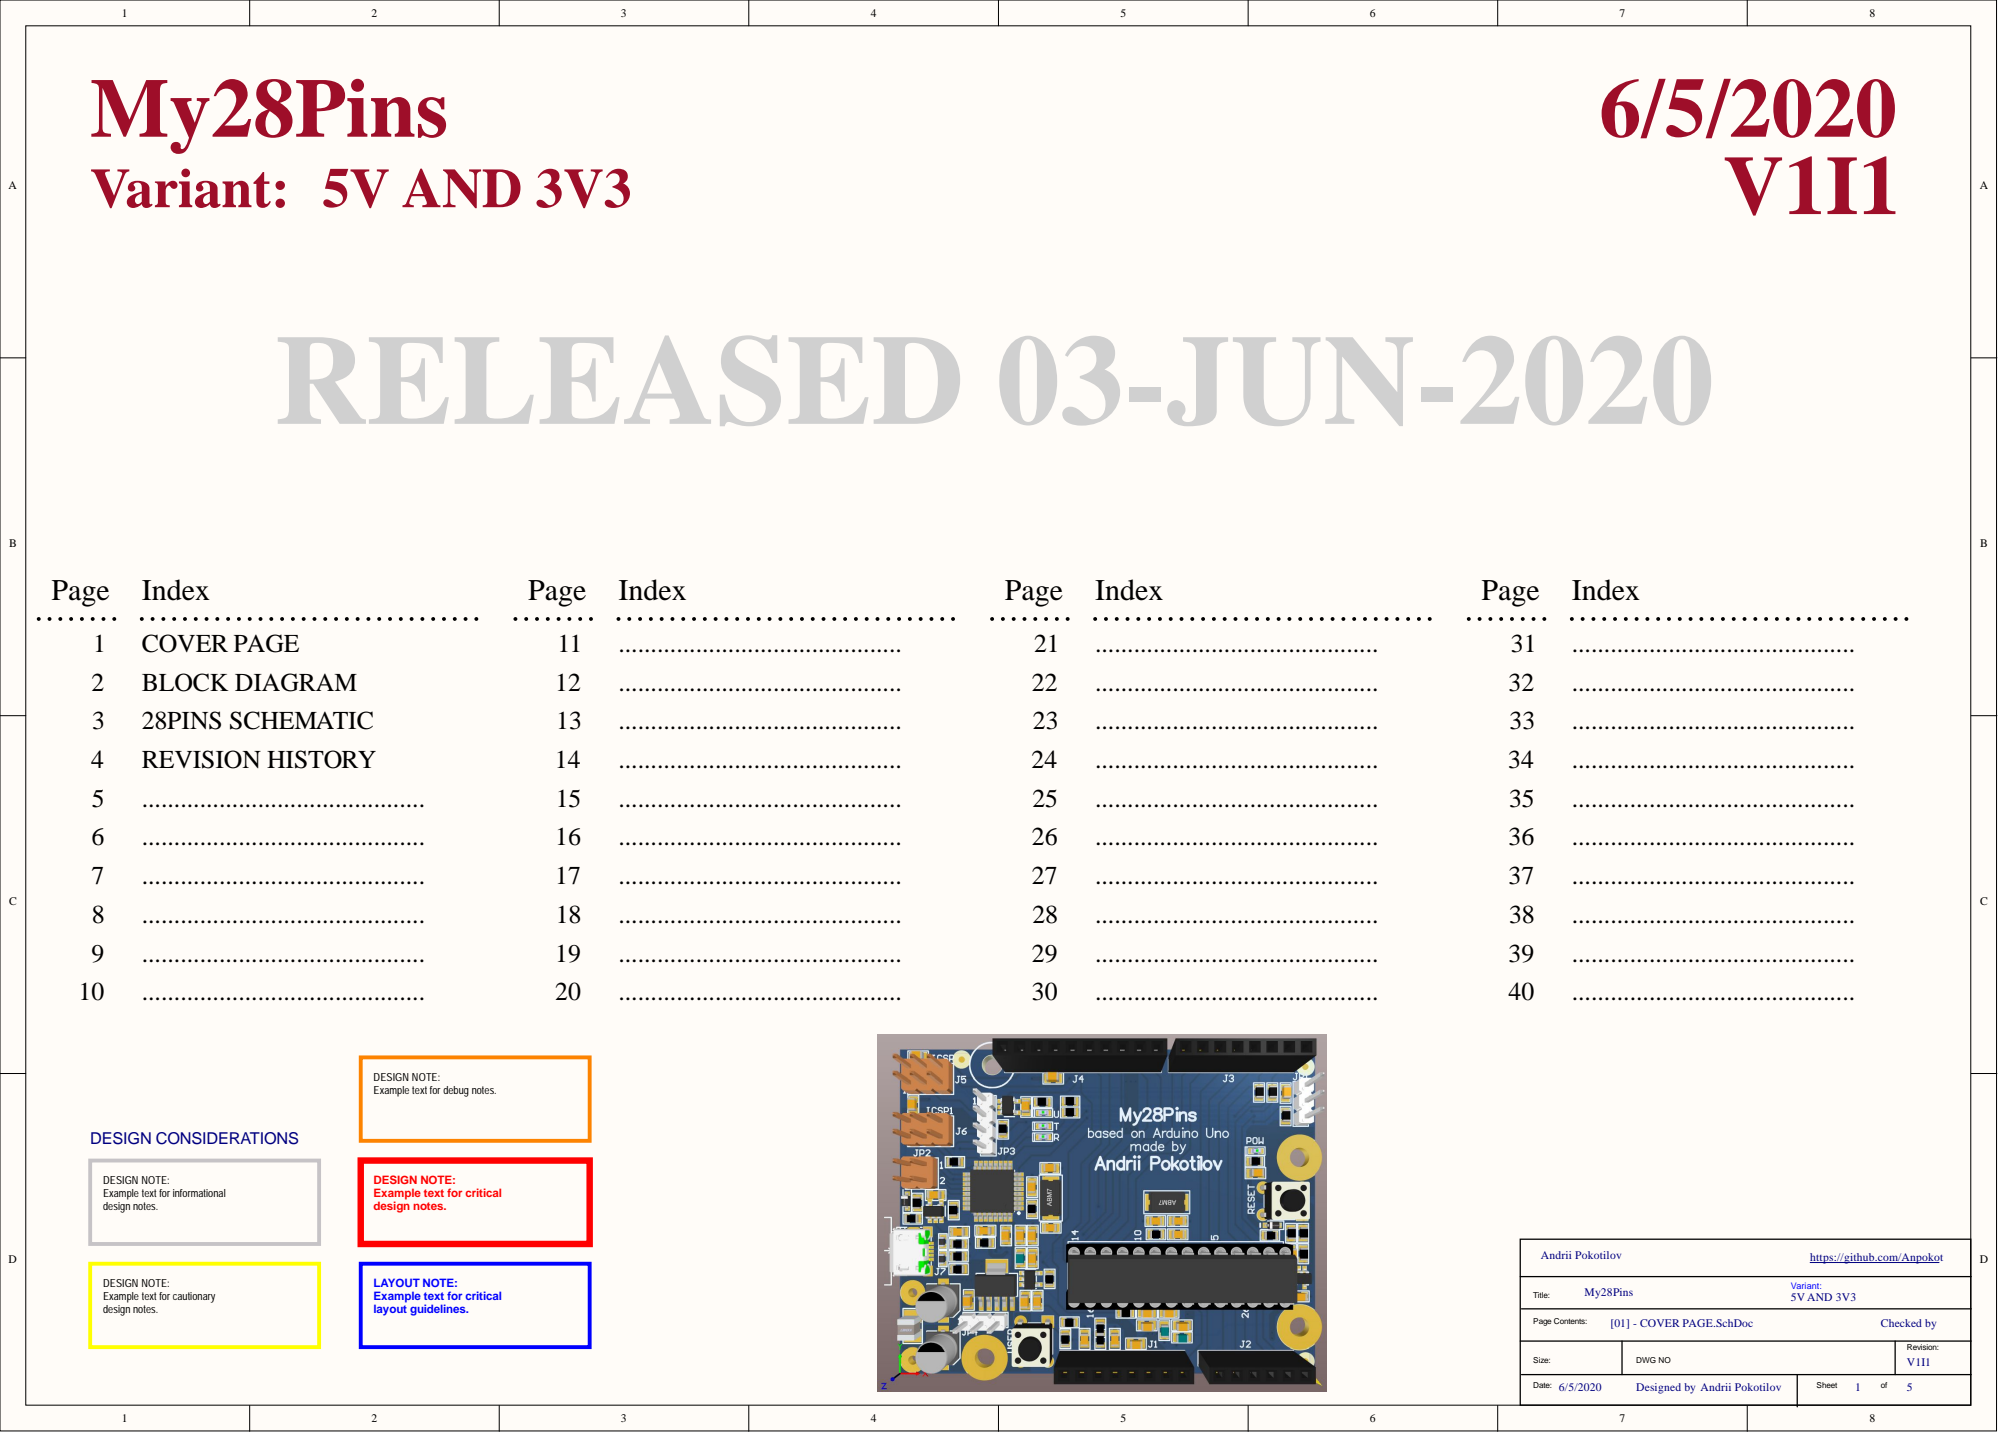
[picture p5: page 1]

DESIGN NOTE:
Example text for debug notes.

Example text for informational
design notes.

Example text for critical

https://github.com/Anpokot

Example text for cautionary

LAYOUT NOTE:
layout guidelines.

Size: | DWG NO | Revision: V1I1

Date: 6/5/2020 Designed by Andrii Pokotilov | Sheet of

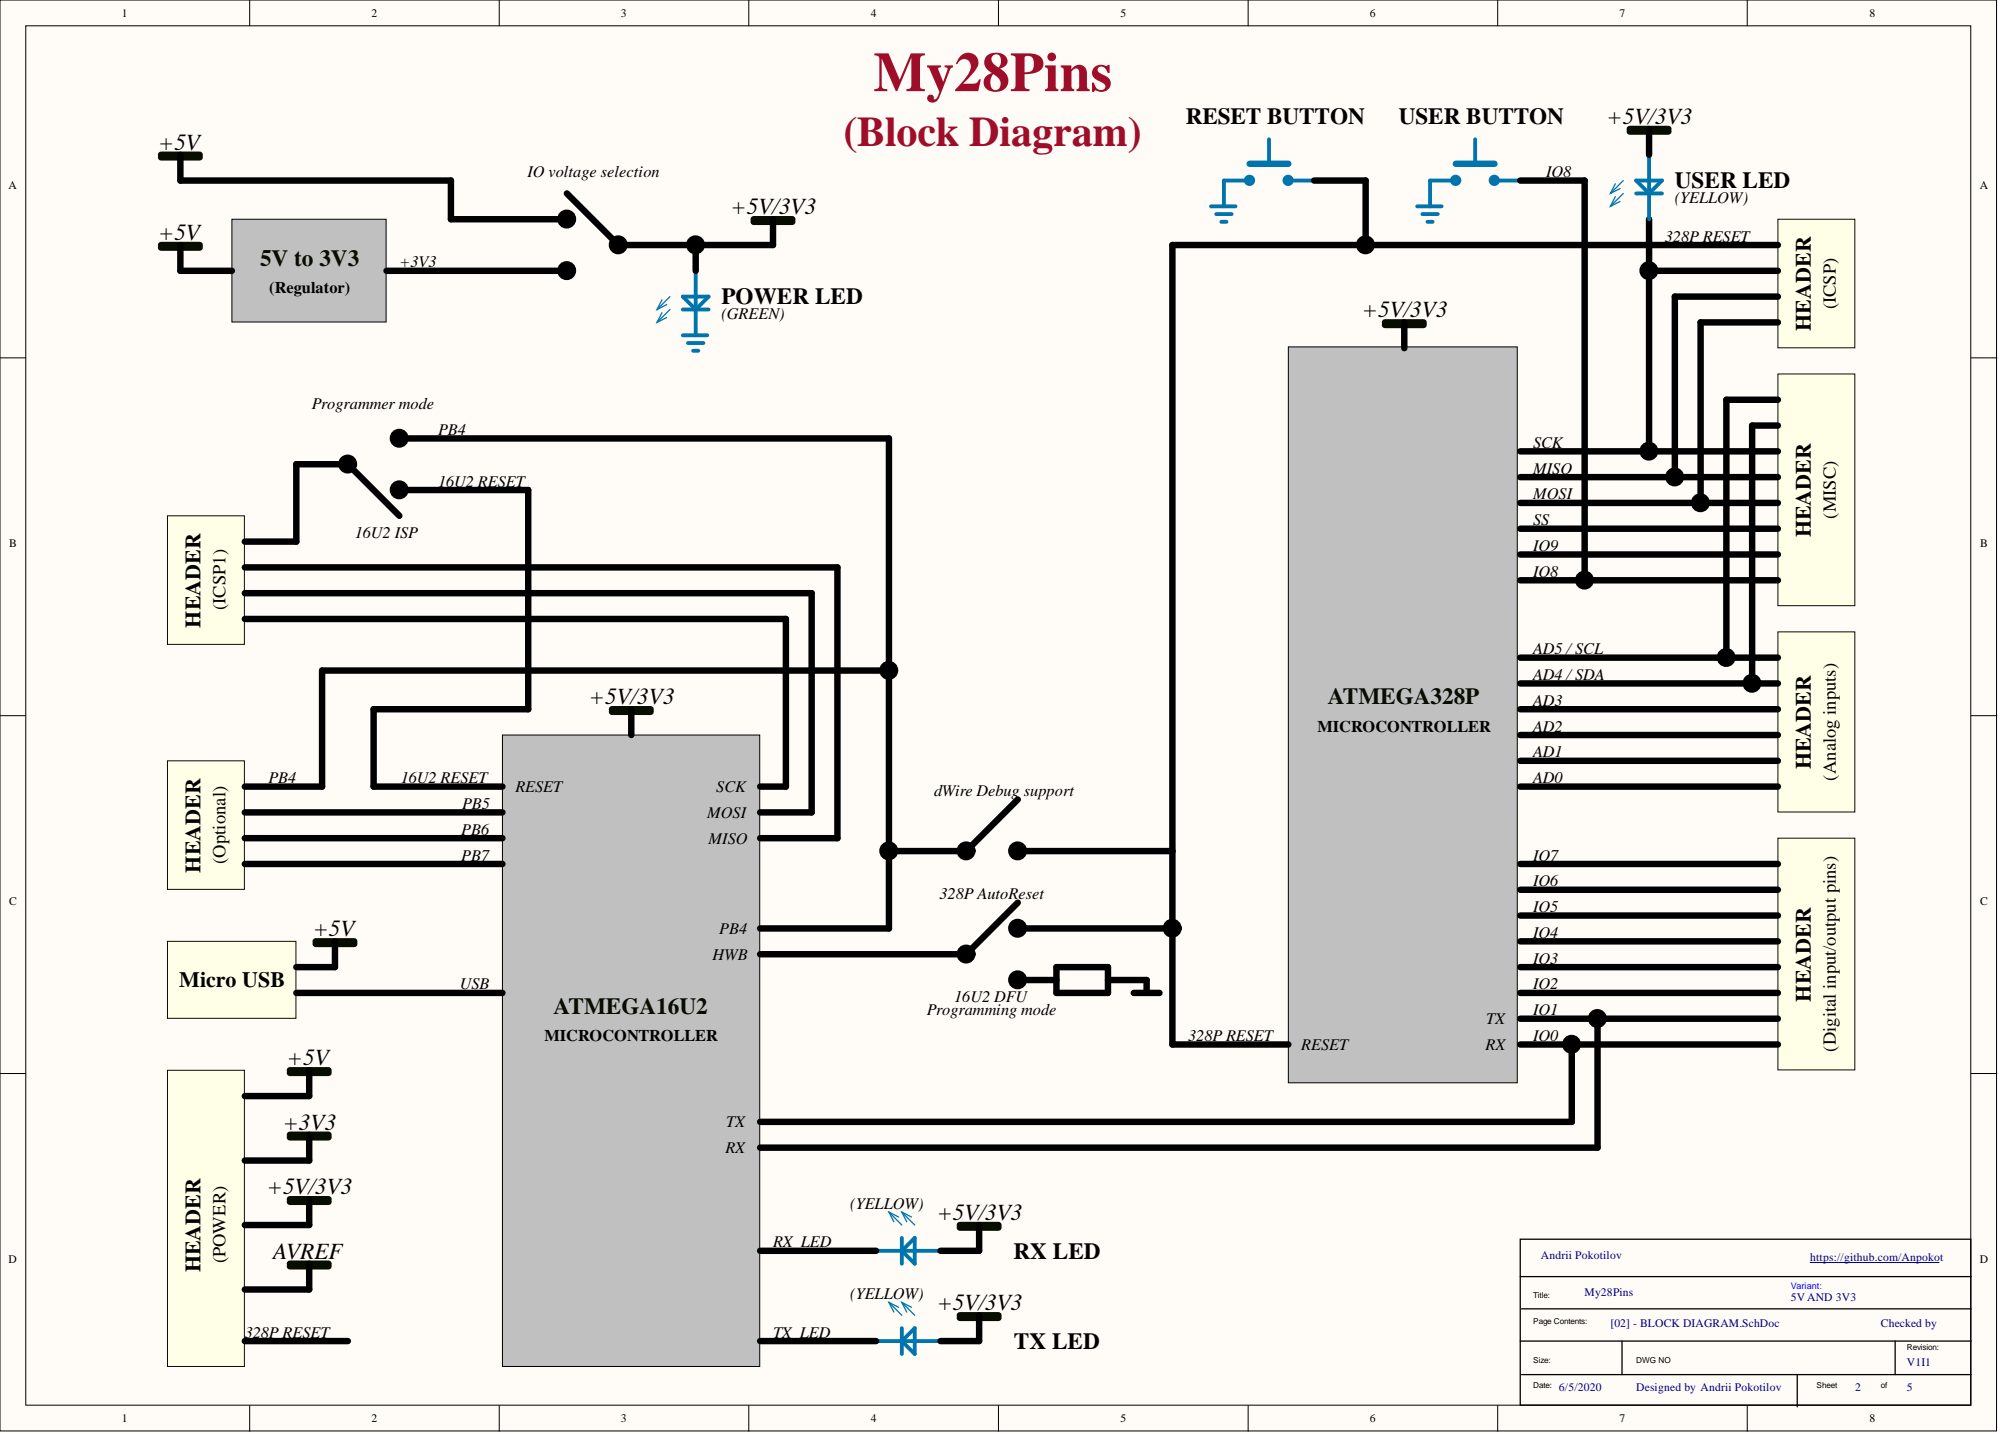
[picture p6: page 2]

MISO
MOSI
SS
IO9
IO8

AD5 / SCL
AD4 / SDA

https://github.com/Anpokot

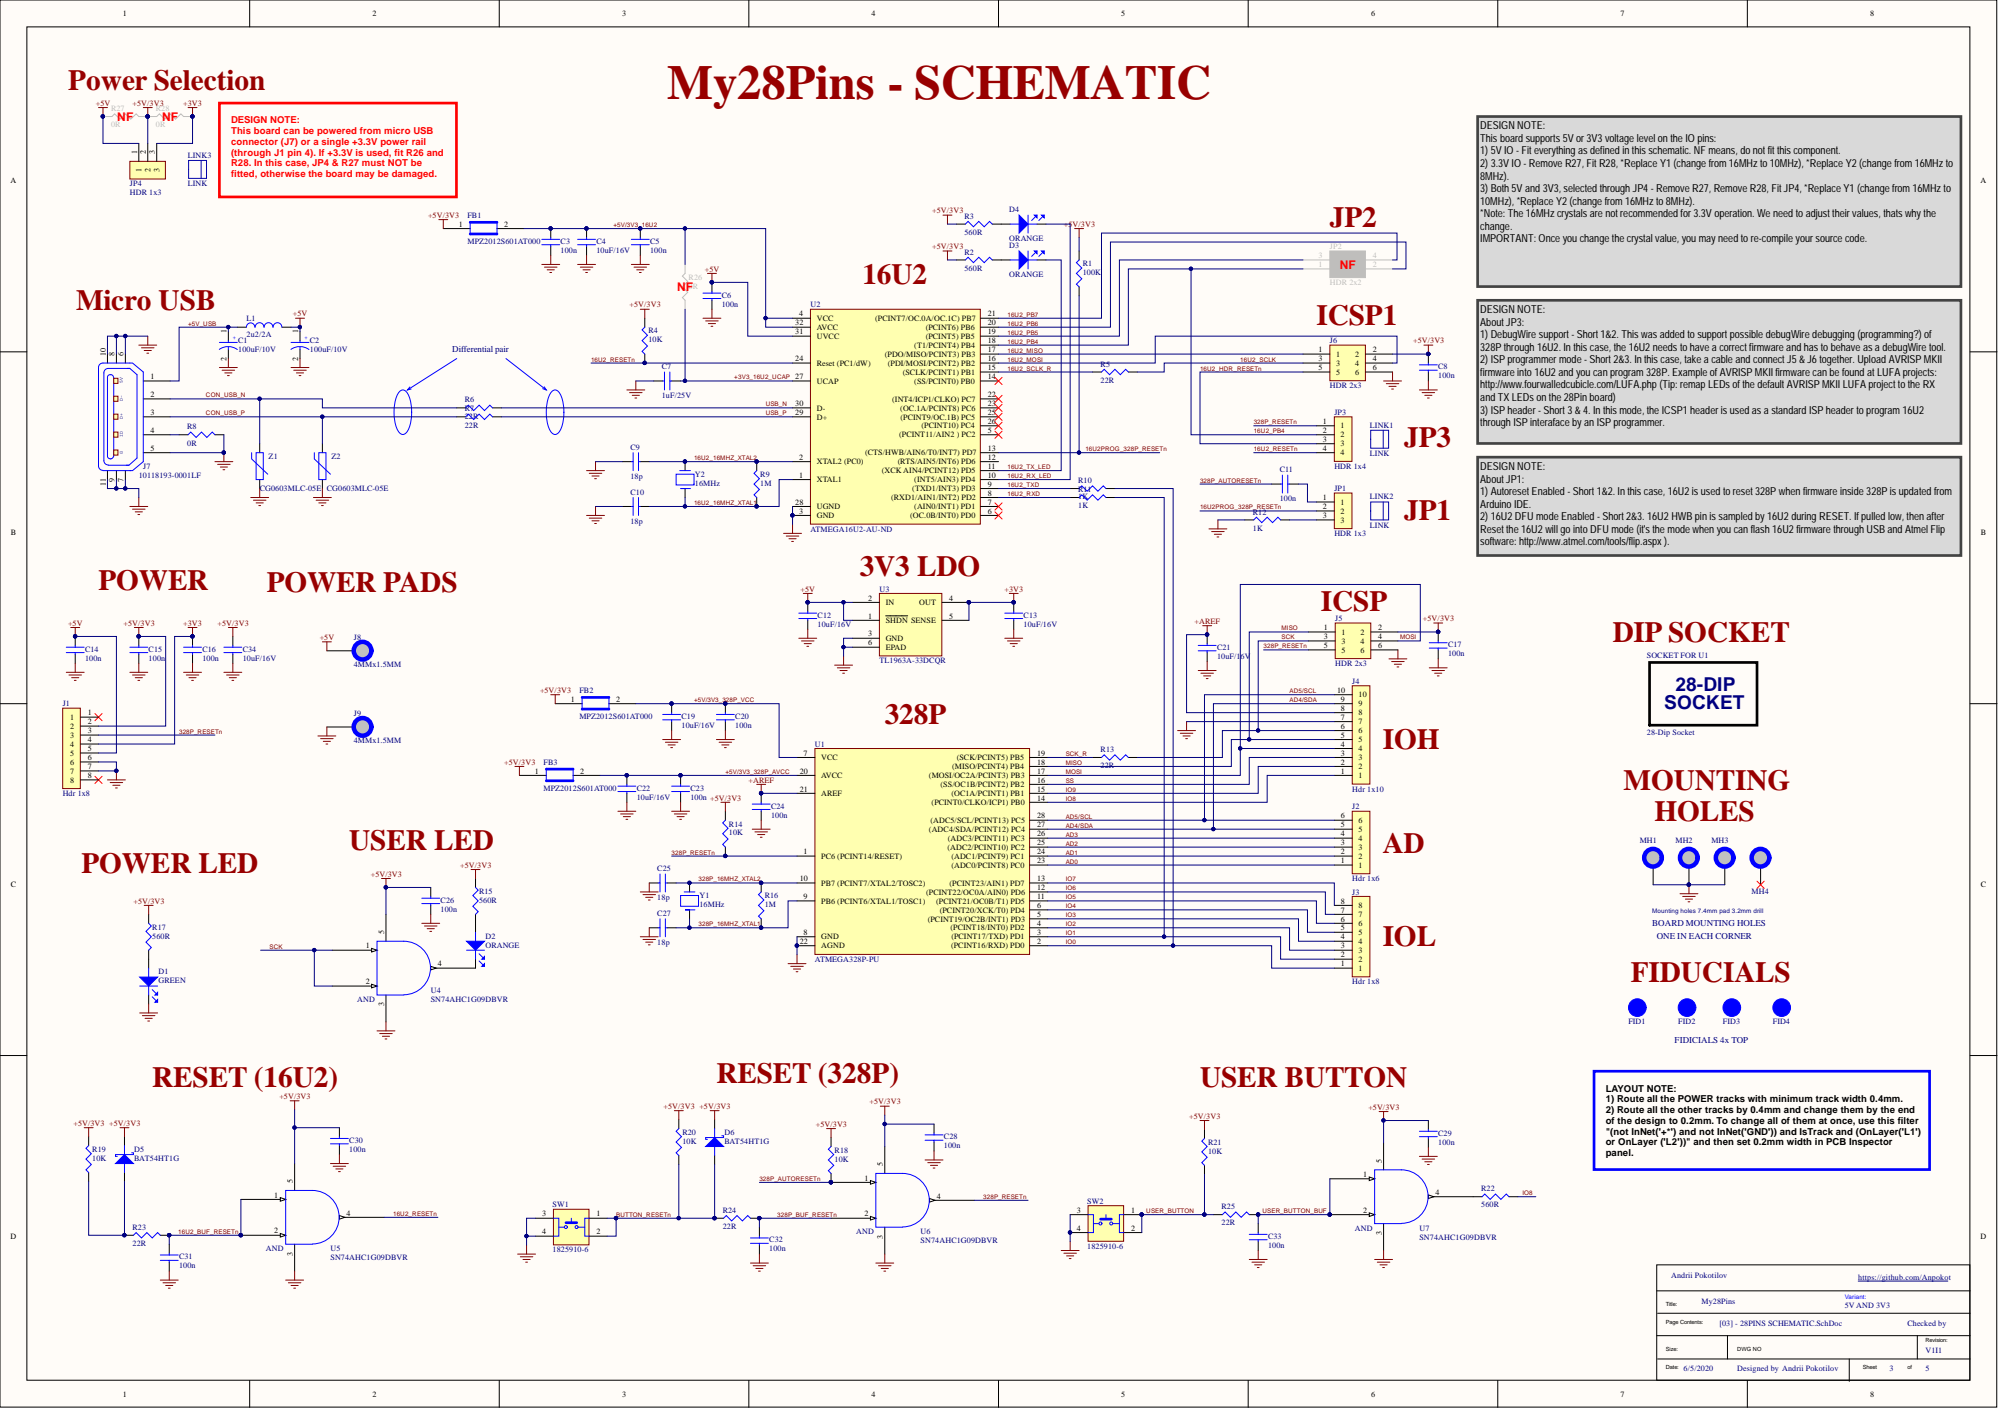
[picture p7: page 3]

DESIGN NOTE:
This board can be powered from micro USB
connector (J7) or a single +3.3V power rail
(through J1 pin 4). If +3.3V is used, fit R26 and
R28. In this case, JP4 & R27 must NOT be
fitted, otherwise the board may be damaged.

This board supports 5V or 3V3 voltage level on the IO pins:
1) 5V IO - Fit everything as defined in this schematic. NF means, do not fit this component.
2) 3.3V IO - Remove R27, Fit R28, *Replace Y1 (change from 16MHz to 10MHz), *Replace Y2 (change from 16MHz to
8MHz).
3) Both 5V and 3V3, selected through JP4 - Remove R27, Remove R28, Fit JP4, *Replace Y1 (change from 16MHz to
10MHz), *Replace Y2 (change from 16MHz to 8MHz).
*Note: The 16MHz crystals are not recommended for 3.3V operation. We need to adjust their values, thats why the
change.
IMPORTANT: Once you change the crystal value, you may need to re-compile your source code.

ORANGE 16U2_PB7 | | 100K

About JP3:
1) DebugWire support - Short 1&2. This was added to support possible debugWire debugging (programming?) of
328P through 16U2. In this case, the 16U2 needs to have a correct firmware and has to behave as a debugWire tool.
2) ISP programmer mode - Short 2&3. In this case, take a cable and connect J5 & J6 together. Upload AVRISP MKII
firmware into 16U2 and you can program 328P. Example of AVRISP MKII firmware can be found at LUFA projects:
http://www.fourwalledcubicle.com/LUFA.php (Tip: remap LEDs of the default AVRISP MKII LUFA project to the RX

Reset (PC1/dW) 24 | | 16U2_PB4 | | | J6

16U2_MISO
16U2_MOSI | | | 16U2_SCLK

+3V3_16U2_UCAP | UCAP 27 | | 16U2_SCLK_R

and TX LEDs on the 28Pin board)
3) ISP header - Short 3 & 4. In this mode, the ICSP1 header is used as a standard ISP header to program 16U2
through ISP interaface by an ISP programmer.

About JP1:
1) Autoreset Enabled - Short 1&2. In this case, 16U2 is used to reset 328P when firmware inside 328P is updated from
Arduino IDE.
2) 16U2 DFU mode Enabled - Short 2&3. 16U2 HWB pin is sampled by 16U2 during RESET. If pulled low, then after
Reset the 16U2 will go into DFU mode (it's the mode when you can flash 16U2 firmware through USB and Atmel Flip
software: http://www.atmel.com/tools/flip.aspx ).

16U2_TX_LED

AVCC 20 | MISO 22R

+AREF | AREF 21 | SS

PC6 (PCINT14/RESET) 1 | | IO8

AD5/SCL
AD4/SDA

AD2
AD1

PB7 (PCINT7/XTAL2/TOSC2) 10 | AD0

IO5
IO3 | | 1 1 2 2 3 3 4 4 5 5 6 6 7 7 8 8
IO4

Mounting holes 7.4mm pad 3.2mm drill
BOARD MOUNTING HOLES
ONE IN EACH CORNER
FIDUCIALS

IO2
IO1
IO0

LAYOUT NOTE:
1) Route all the POWER tracks with minimum track width 0.4mm.
2) Route all the other tracks by 0.4mm and change them by the end
of the design to 0.2mm. To change all of them at once, use this filter
"(not InNet('+*') and not InNet('GND')) and IsTrack and (OnLayer('L1')
or OnLayer ('L2'))" and then set 0.2mm width in PCB Inspector
panel.

https://github.com/Anpokot

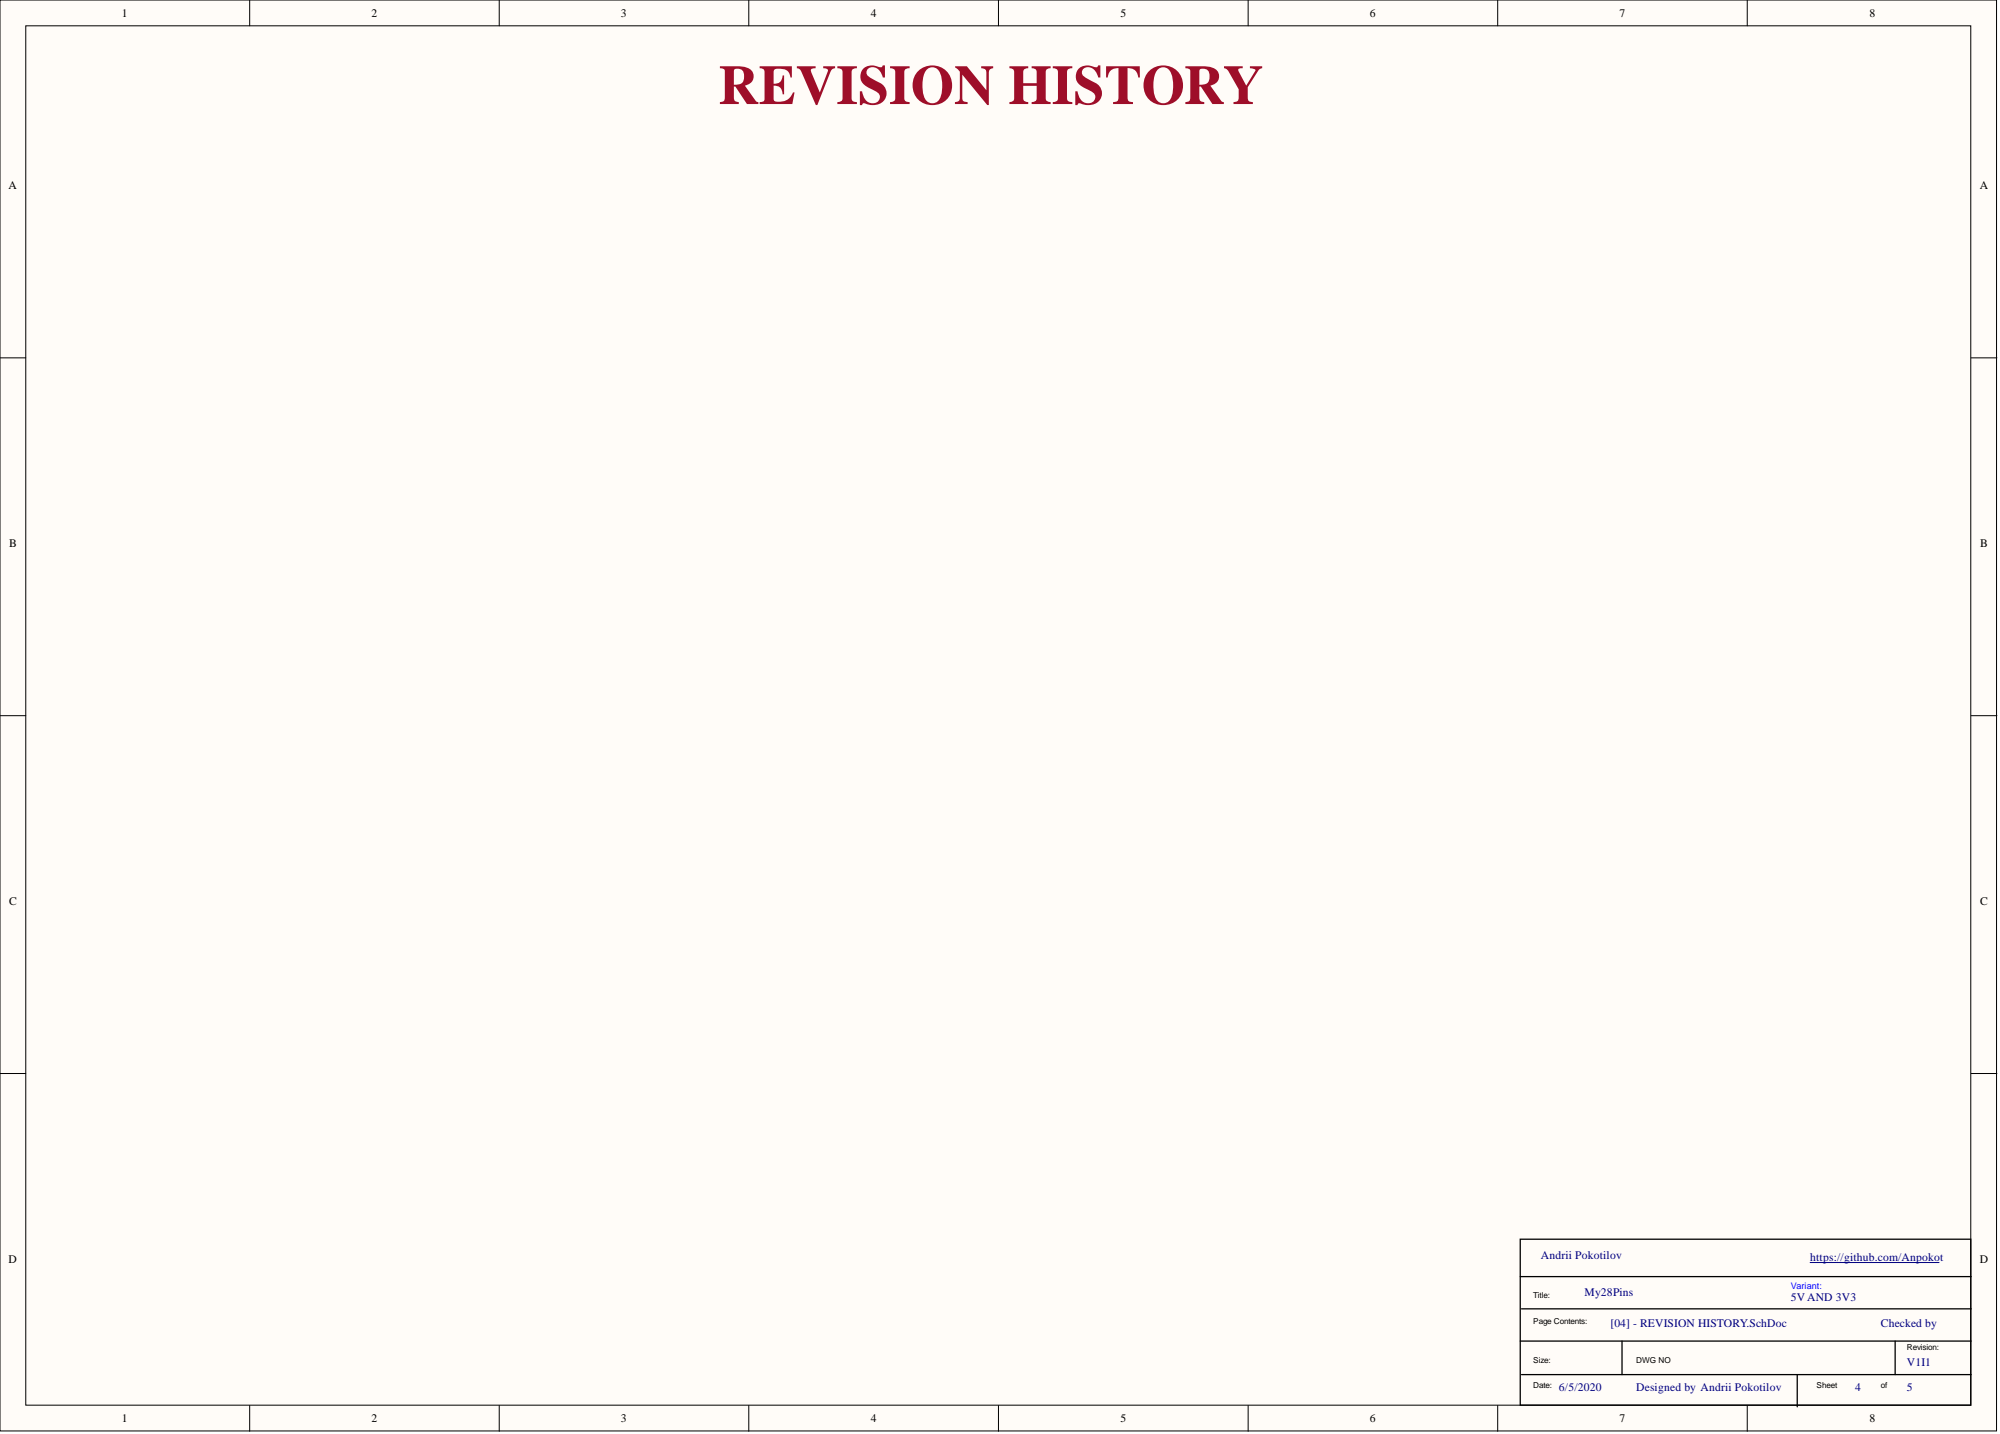
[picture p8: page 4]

https://github.com/Anpokot

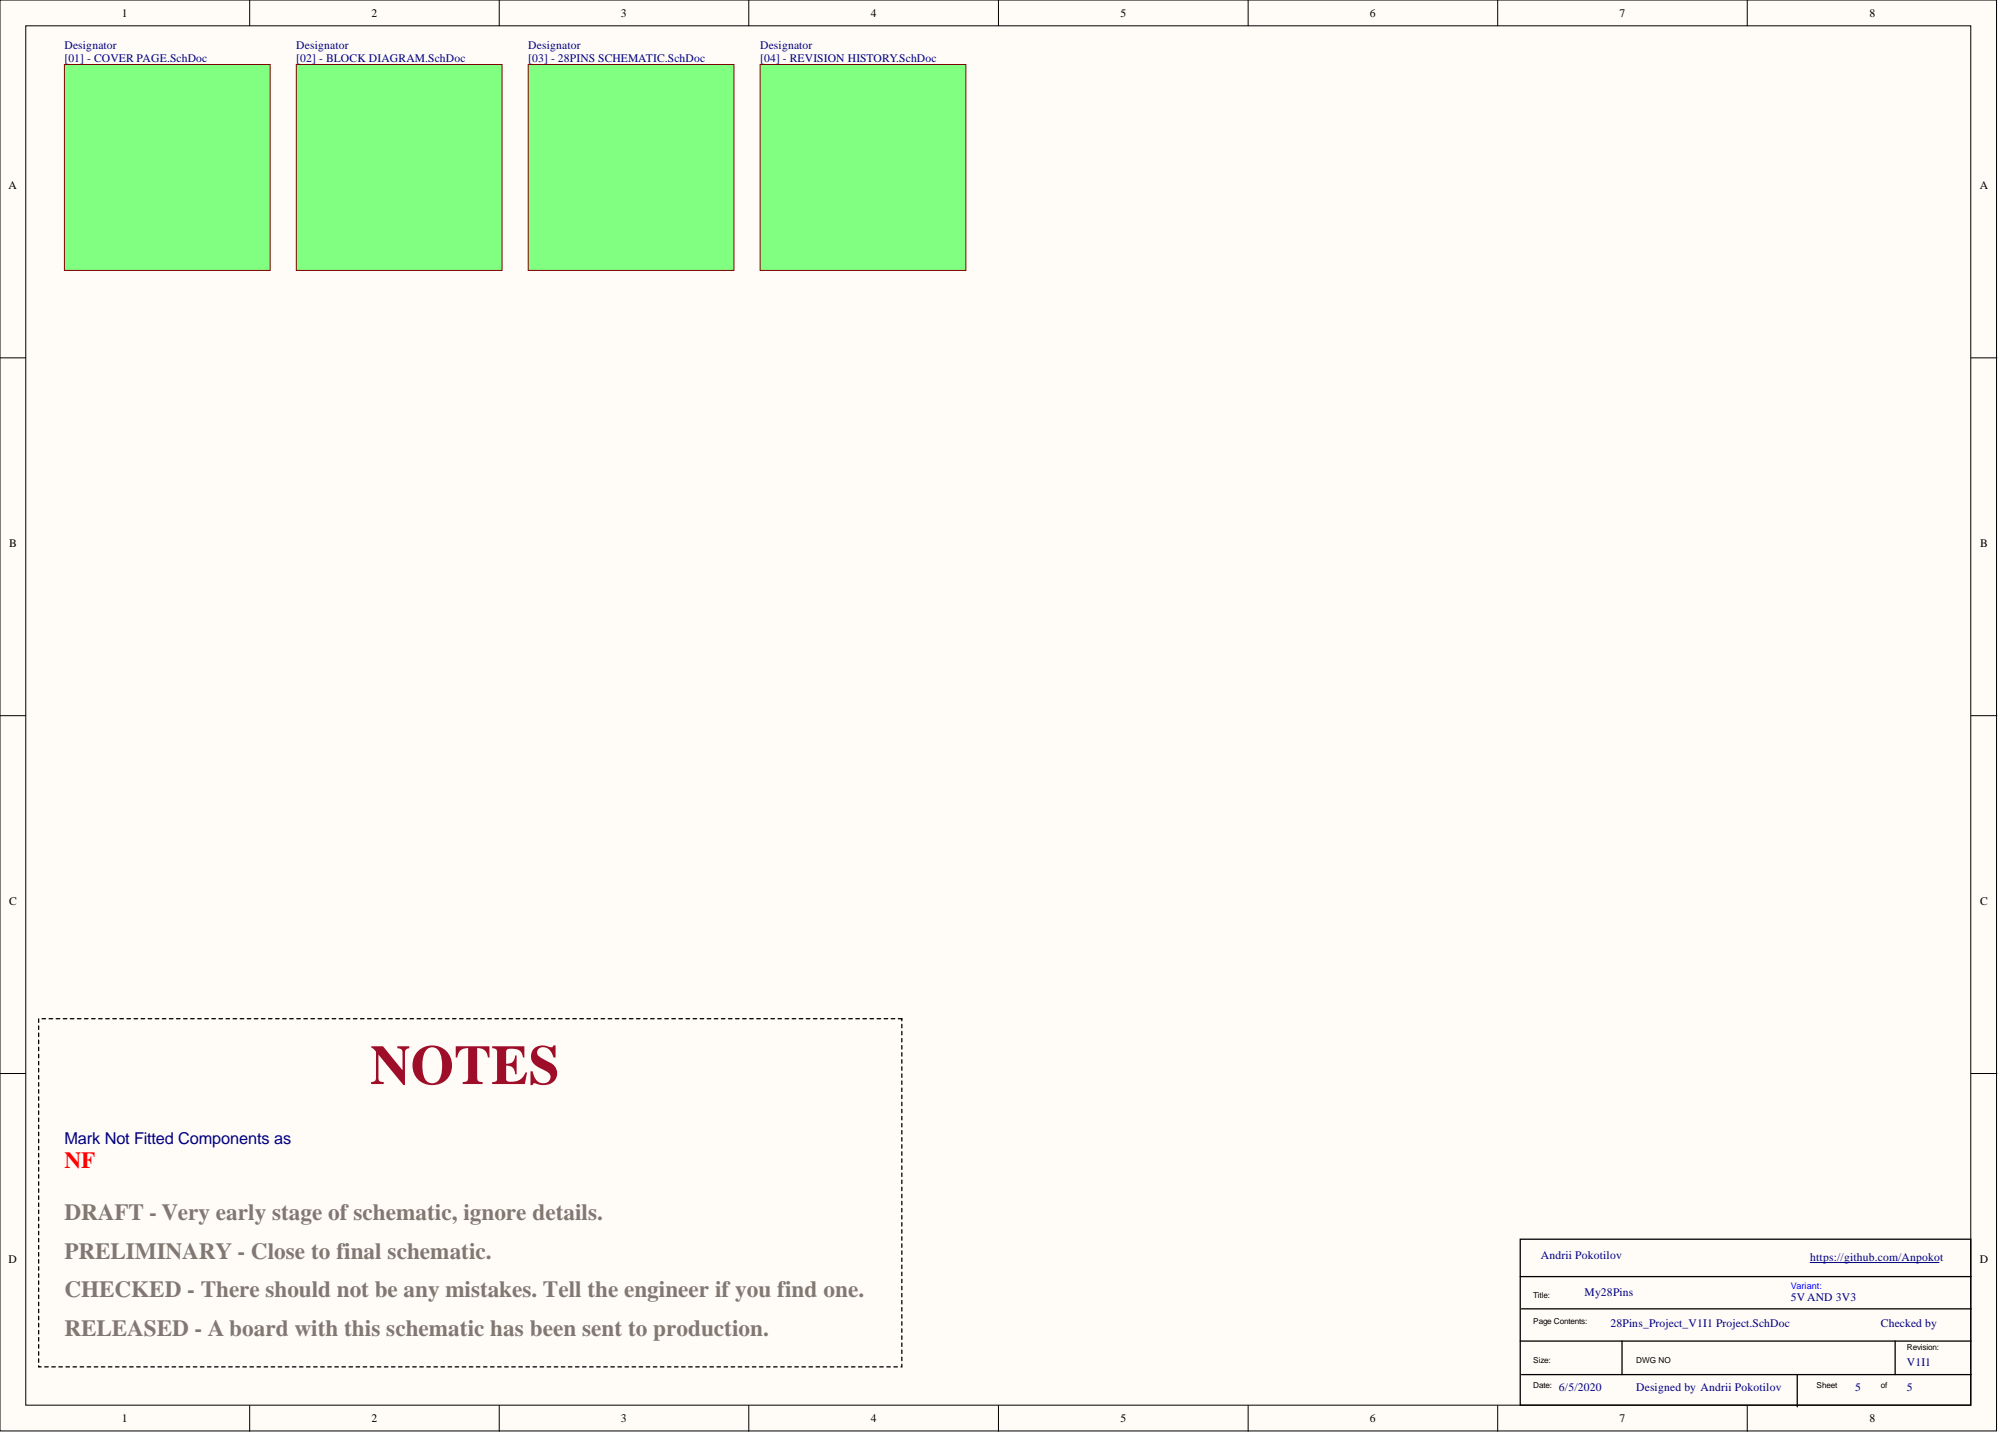
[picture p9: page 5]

Mark Not Fitted Components as

DRAFT - Very early stage of schematic, ignore details.
PRELIMINARY - Close to final schematic.
CHECKED - There should not be any mistakes. Tell the engineer if you find one.
RELEASED - A board with this schematic has been sent to production.

https://github.com/Anpokot

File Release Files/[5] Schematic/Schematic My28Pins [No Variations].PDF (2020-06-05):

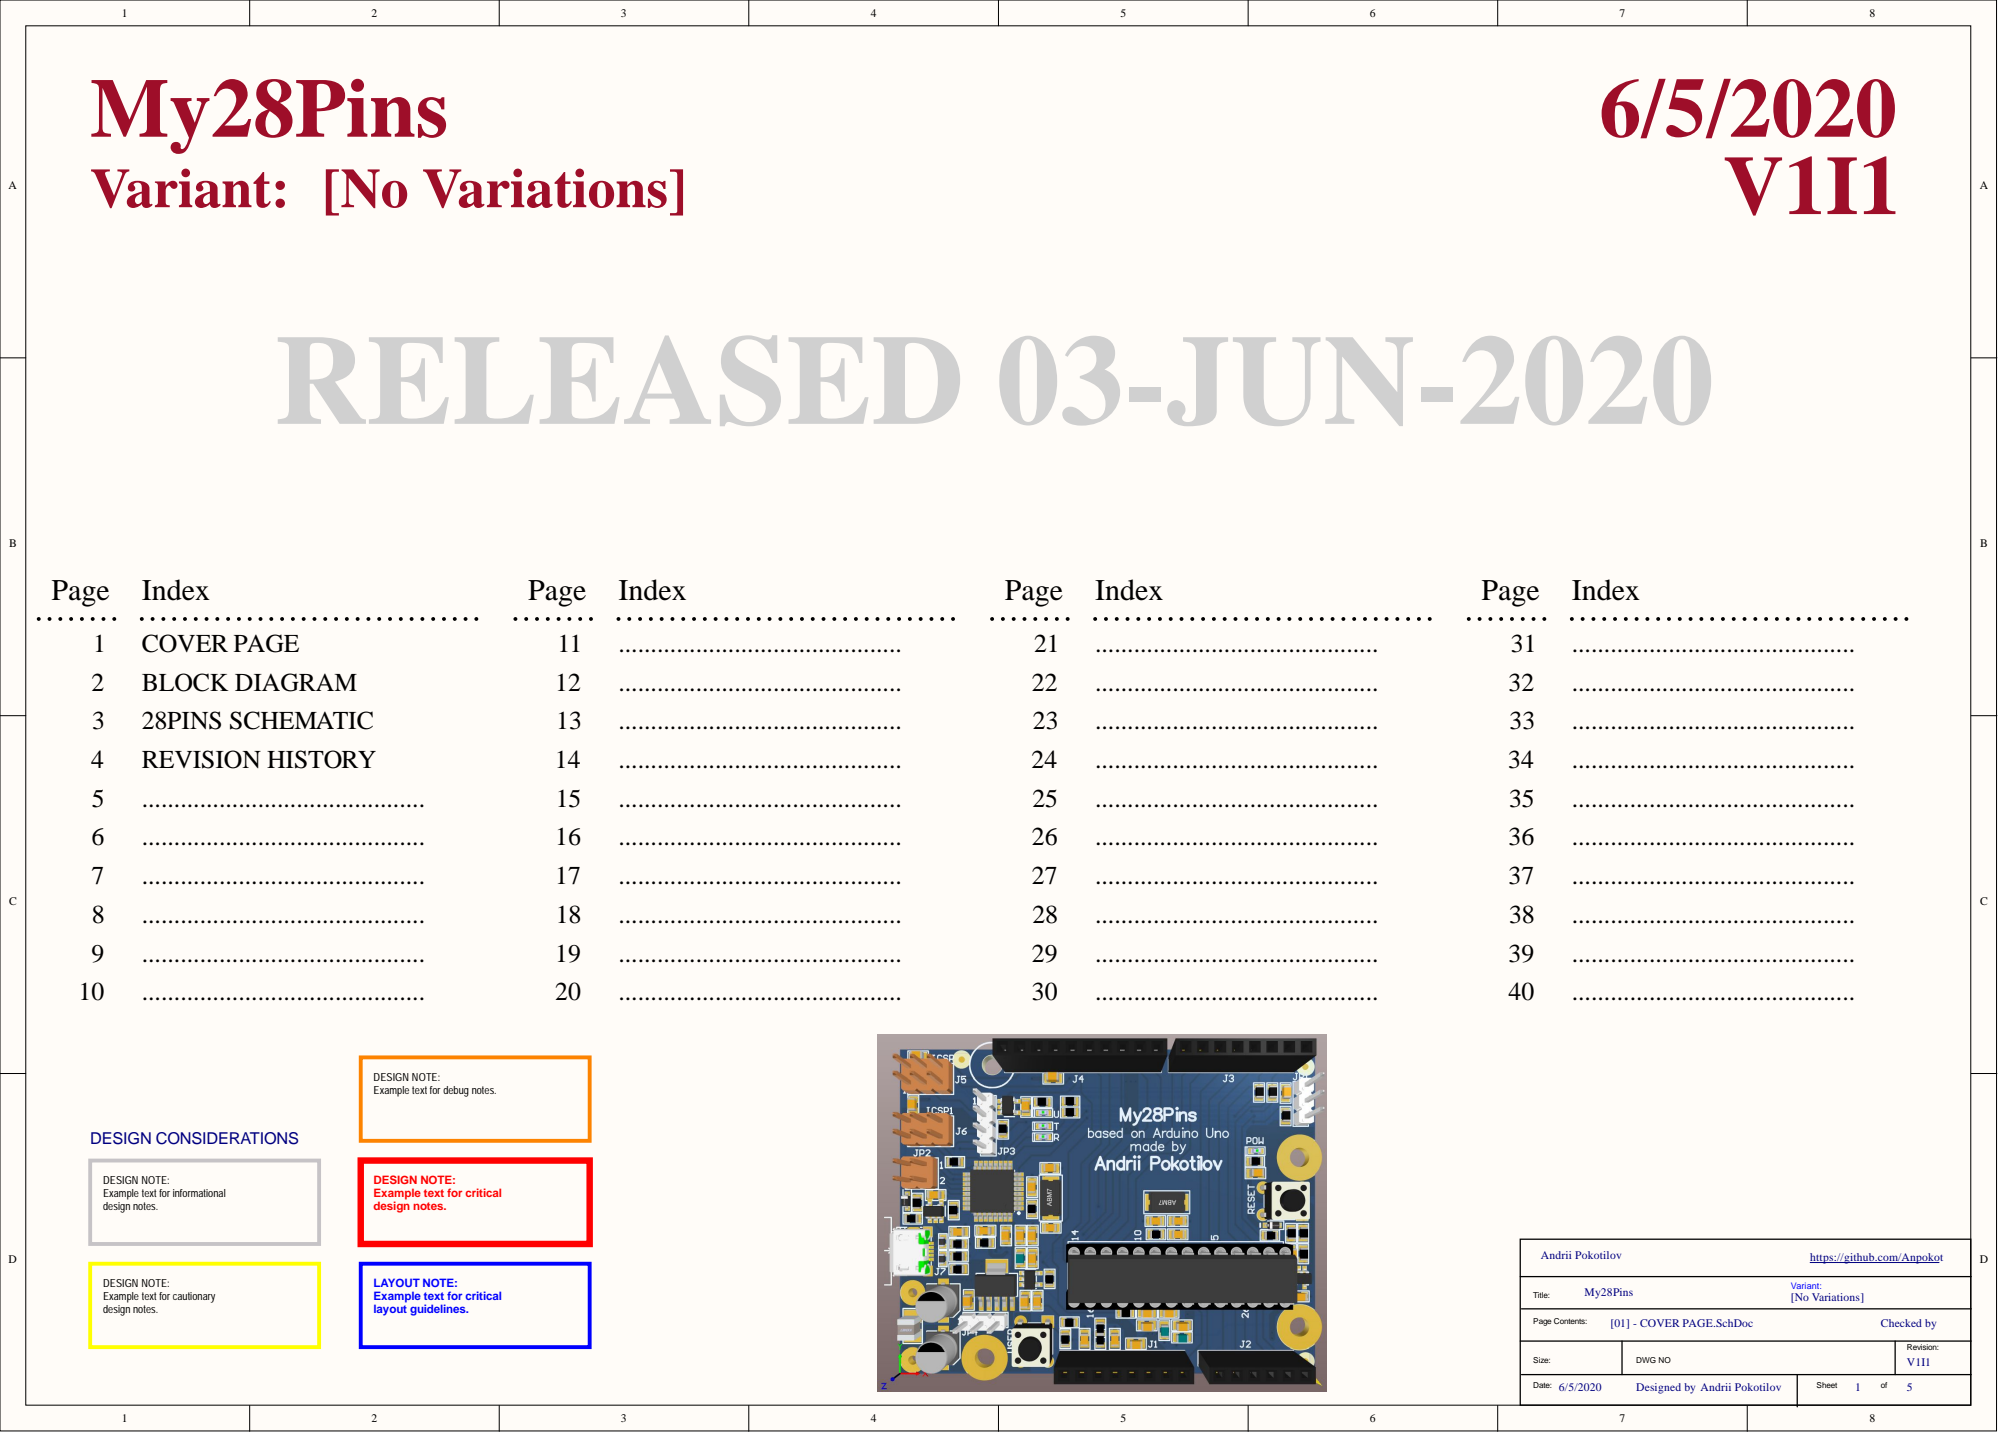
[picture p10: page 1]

DESIGN NOTE:
Example text for debug notes.

Example text for informational
design notes.

Example text for critical

https://github.com/Anpokot

Example text for cautionary

LAYOUT NOTE:
layout guidelines.

Size: | DWG NO | Revision: V1I1

Date: 6/5/2020 Designed by Andrii Pokotilov | Sheet of

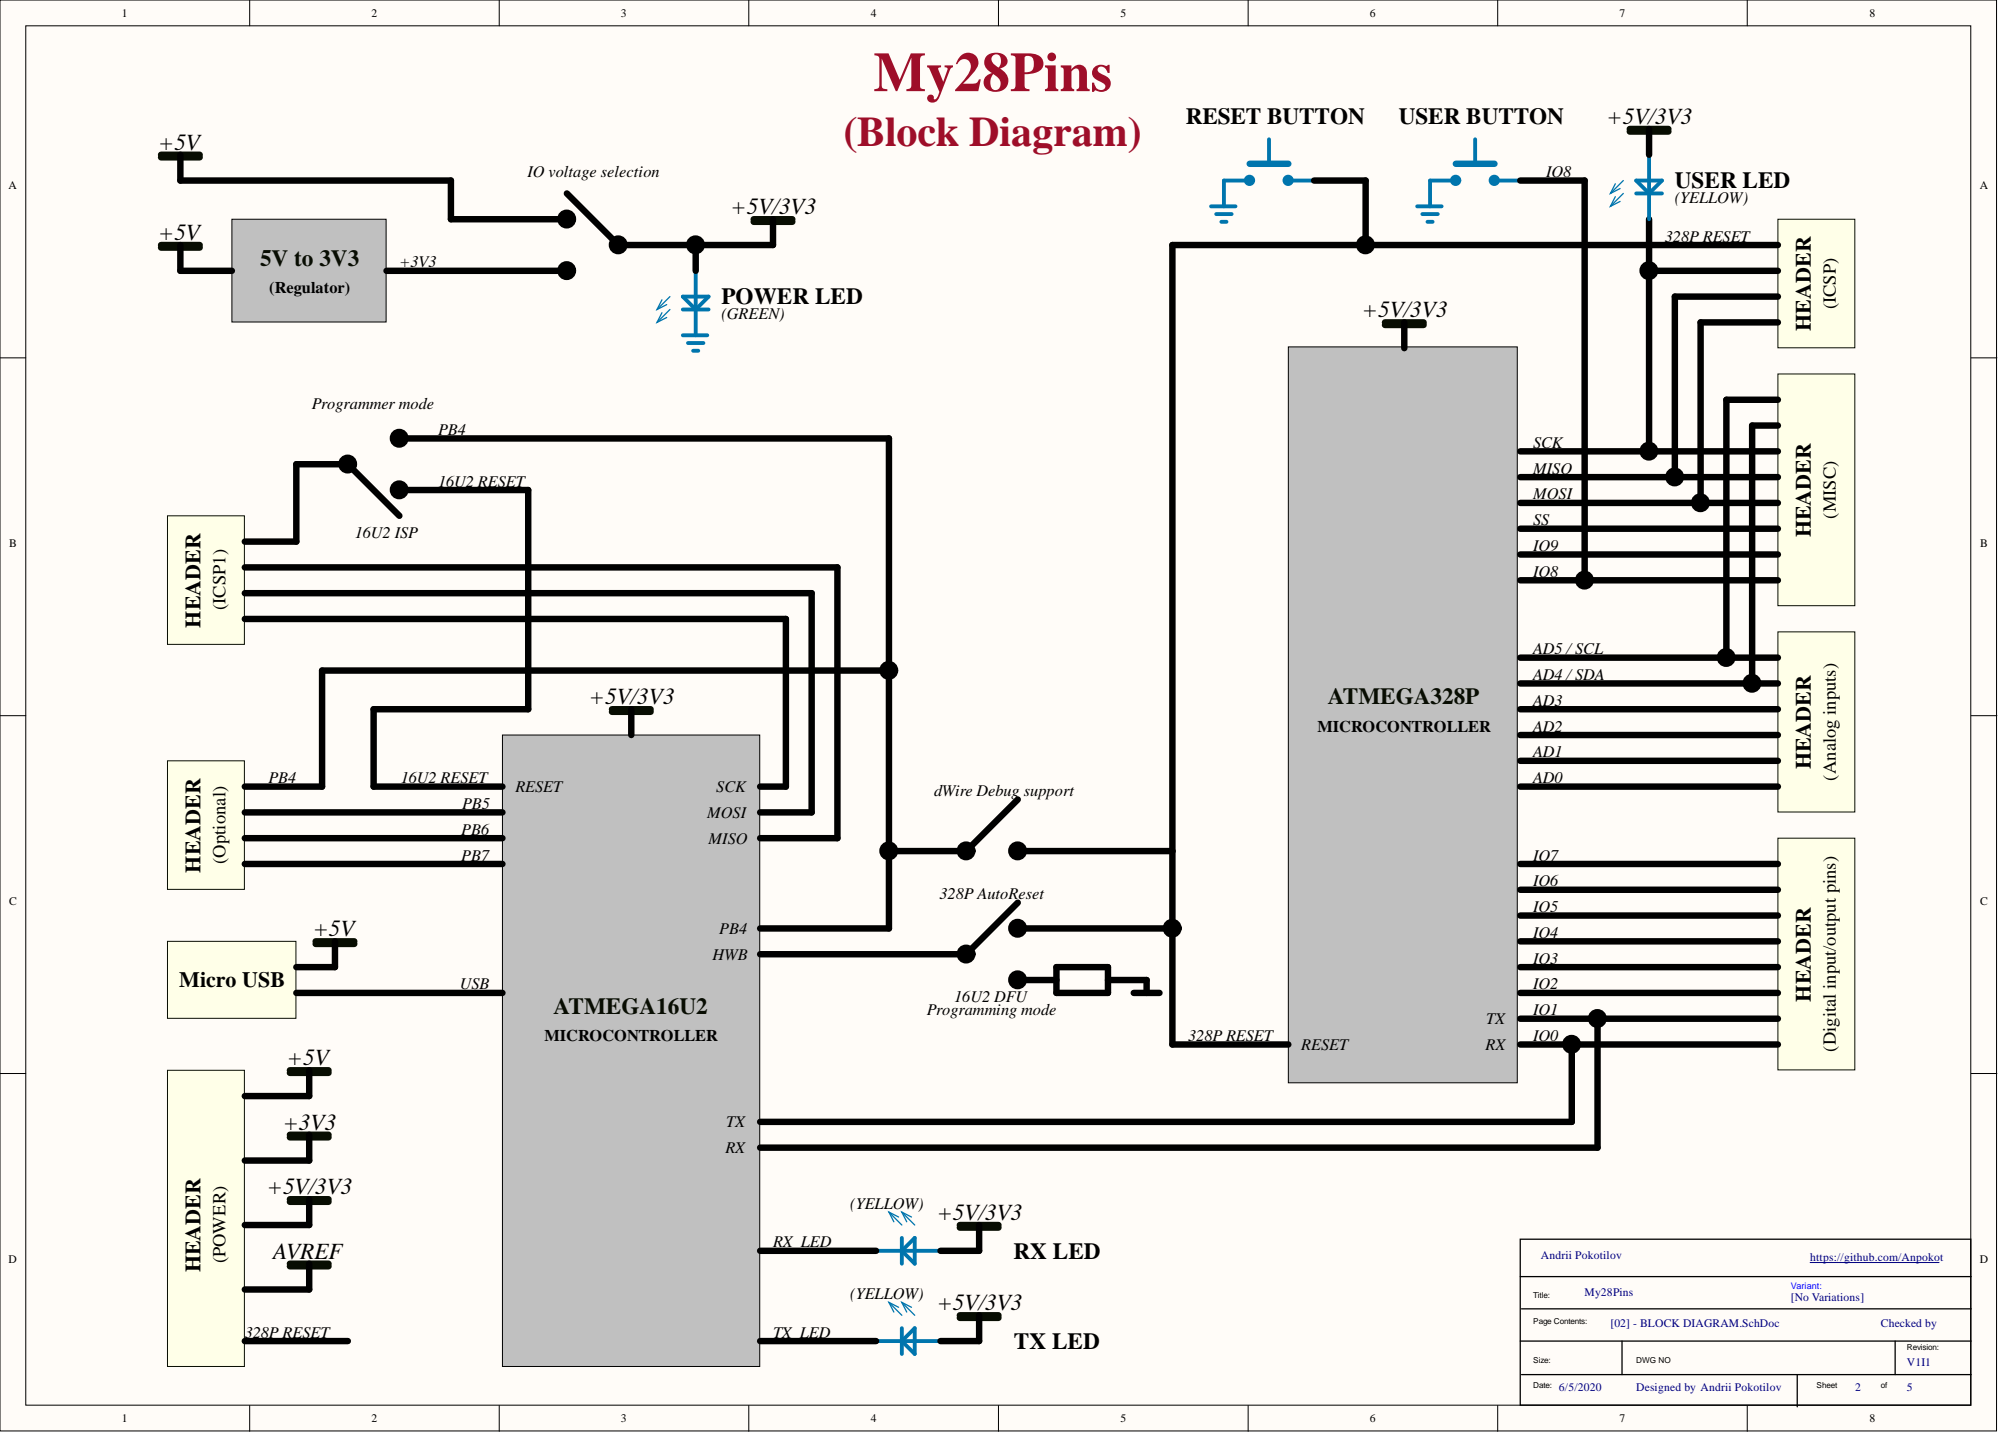
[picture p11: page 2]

MISO
MOSI
SS
IO9
IO8

AD5 / SCL
AD4 / SDA

https://github.com/Anpokot

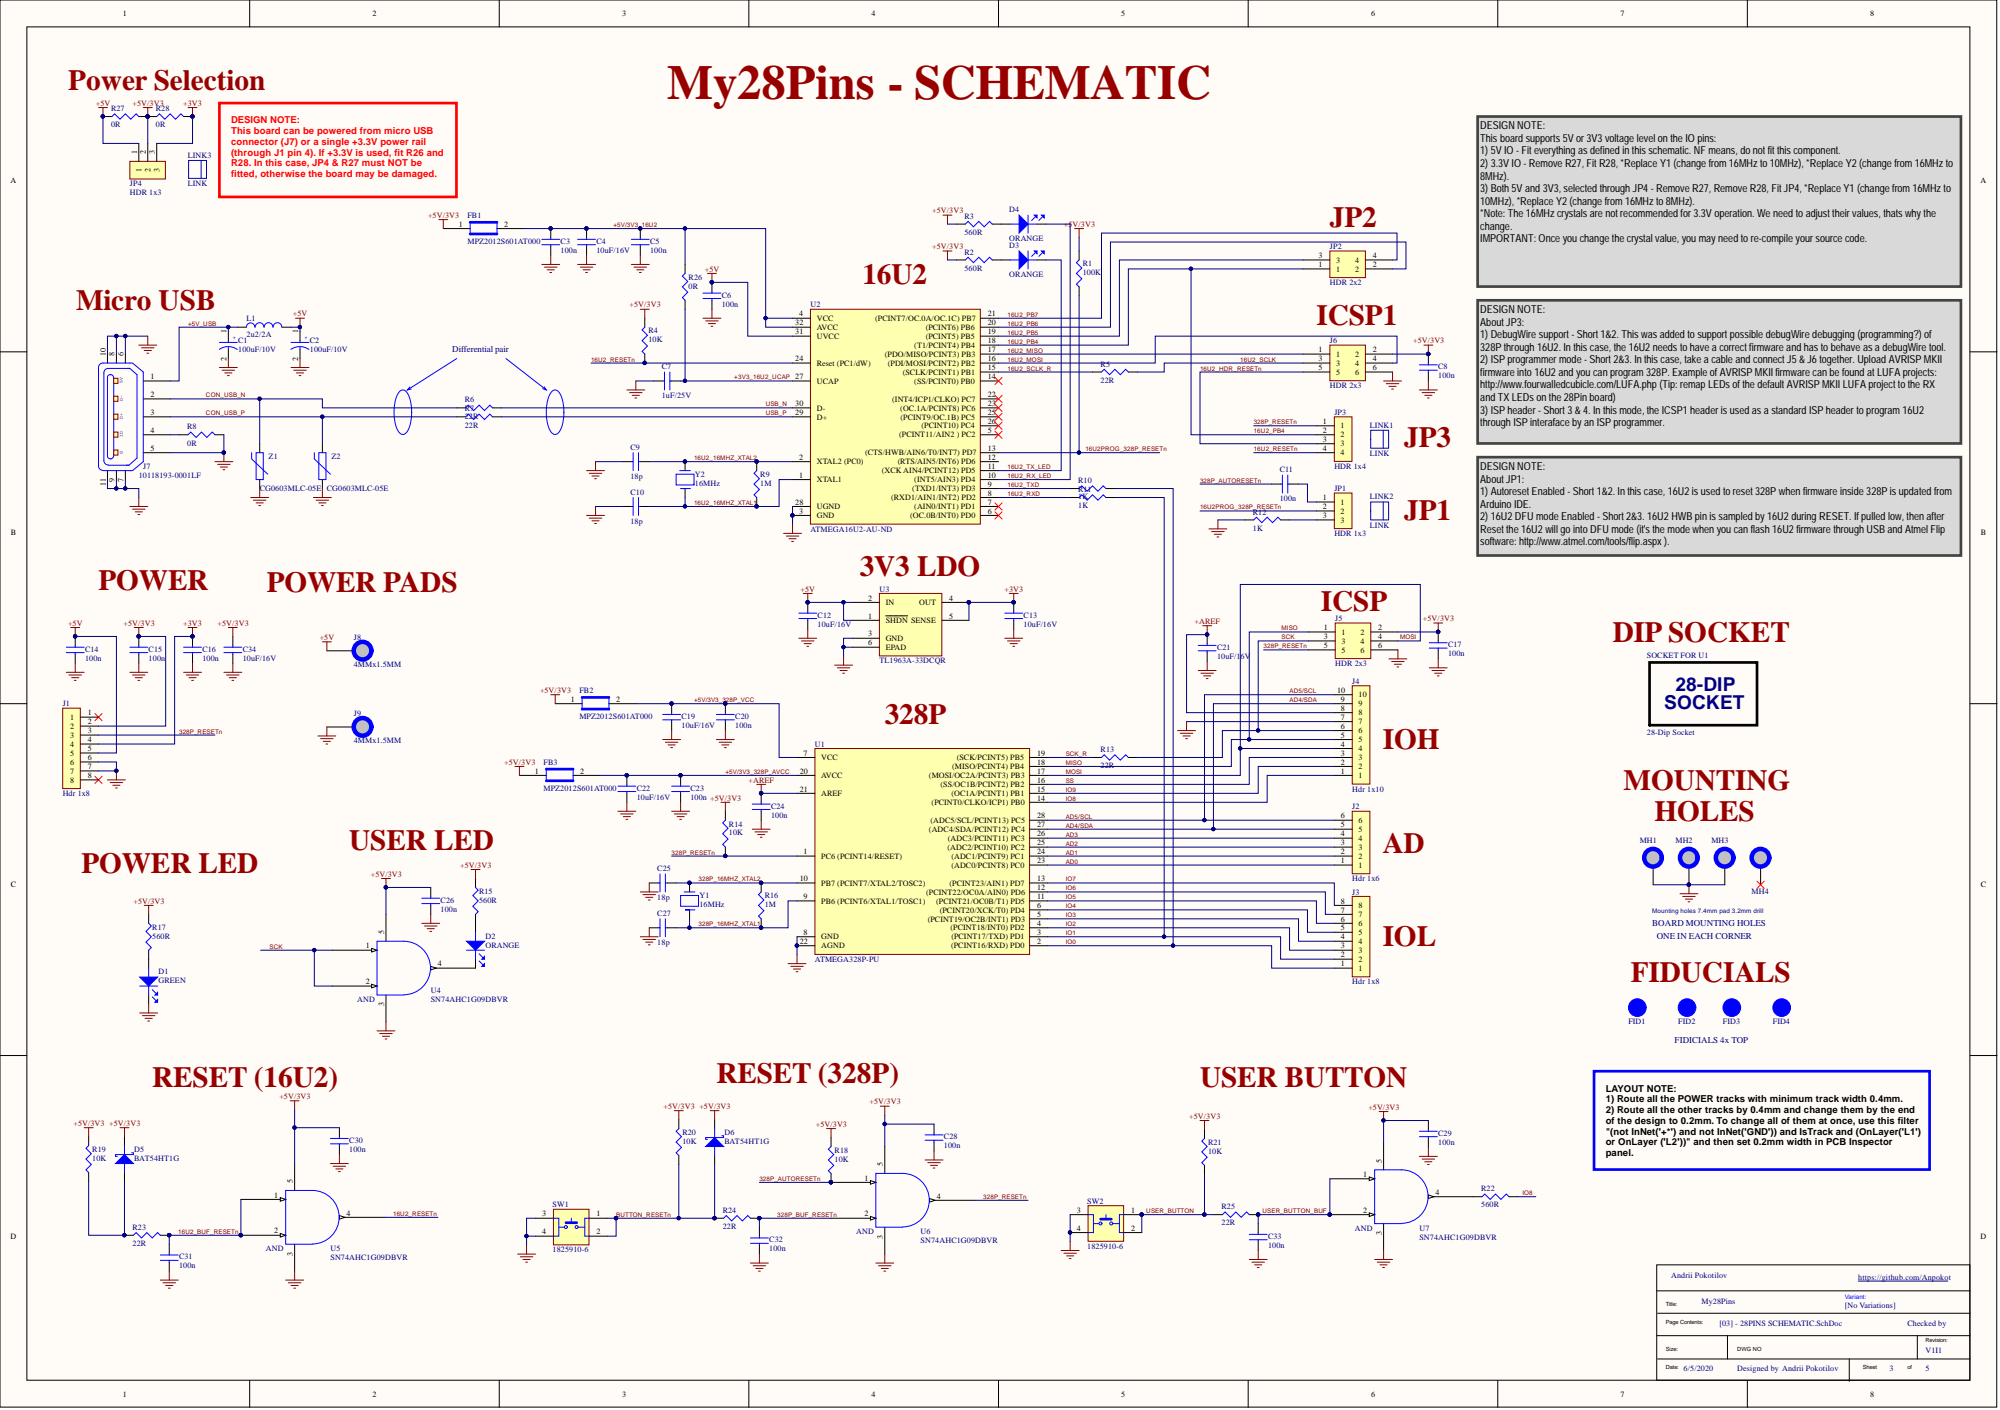
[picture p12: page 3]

DESIGN NOTE:
This board can be powered from micro USB
connector (J7) or a single +3.3V power rail
(through J1 pin 4). If +3.3V is used, fit R26 and
R28. In this case, JP4 & R27 must NOT be
fitted, otherwise the board may be damaged.

This board supports 5V or 3V3 voltage level on the IO pins:
1) 5V IO - Fit everything as defined in this schematic. NF means, do not fit this component.
2) 3.3V IO - Remove R27, Fit R28, *Replace Y1 (change from 16MHz to 10MHz), *Replace Y2 (change from 16MHz to
8MHz).
3) Both 5V and 3V3, selected through JP4 - Remove R27, Remove R28, Fit JP4, *Replace Y1 (change from 16MHz to
10MHz), *Replace Y2 (change from 16MHz to 8MHz).
*Note: The 16MHz crystals are not recommended for 3.3V operation. We need to adjust their values, thats why the
change.
IMPORTANT: Once you change the crystal value, you may need to re-compile your source code.

ORANGE 16U2_PB7 | | 100K

About JP3:
1) DebugWire support - Short 1&2. This was added to support possible debugWire debugging (programming?) of
328P through 16U2. In this case, the 16U2 needs to have a correct firmware and has to behave as a debugWire tool.
2) ISP programmer mode - Short 2&3. In this case, take a cable and connect J5 & J6 together. Upload AVRISP MKII
firmware into 16U2 and you can program 328P. Example of AVRISP MKII firmware can be found at LUFA projects:
http://www.fourwalledcubicle.com/LUFA.php (Tip: remap LEDs of the default AVRISP MKII LUFA project to the RX

Reset (PC1/dW) 24 | | 16U2_PB4 | | | J6

16U2_MISO
16U2_MOSI | | | 16U2_SCLK

+3V3_16U2_UCAP | UCAP 27 | | 16U2_SCLK_R

and TX LEDs on the 28Pin board)
3) ISP header - Short 3 & 4. In this mode, the ICSP1 header is used as a standard ISP header to program 16U2
through ISP interaface by an ISP programmer.

About JP1:
1) Autoreset Enabled - Short 1&2. In this case, 16U2 is used to reset 328P when firmware inside 328P is updated from
Arduino IDE.
2) 16U2 DFU mode Enabled - Short 2&3. 16U2 HWB pin is sampled by 16U2 during RESET. If pulled low, then after
Reset the 16U2 will go into DFU mode (it's the mode when you can flash 16U2 firmware through USB and Atmel Flip
software: http://www.atmel.com/tools/flip.aspx ).

16U2_TX_LED

AVCC 20 | MISO 22R

+AREF | AREF 21 | SS

PC6 (PCINT14/RESET) 1 | | IO8

AD5/SCL
AD4/SDA

AD2
AD1

PB7 (PCINT7/XTAL2/TOSC2) 10 | AD0

IO5
IO3 | | 1 1 2 2 3 3 4 4 5 5 6 6 7 7 8 8
IO4

Mounting holes 7.4mm pad 3.2mm drill
BOARD MOUNTING HOLES
ONE IN EACH CORNER
FIDUCIALS

IO2
IO1
IO0

LAYOUT NOTE:
1) Route all the POWER tracks with minimum track width 0.4mm.
2) Route all the other tracks by 0.4mm and change them by the end
of the design to 0.2mm. To change all of them at once, use this filter
"(not InNet('+*') and not InNet('GND')) and IsTrack and (OnLayer('L1')
or OnLayer ('L2'))" and then set 0.2mm width in PCB Inspector
panel.

https://github.com/Anpokot

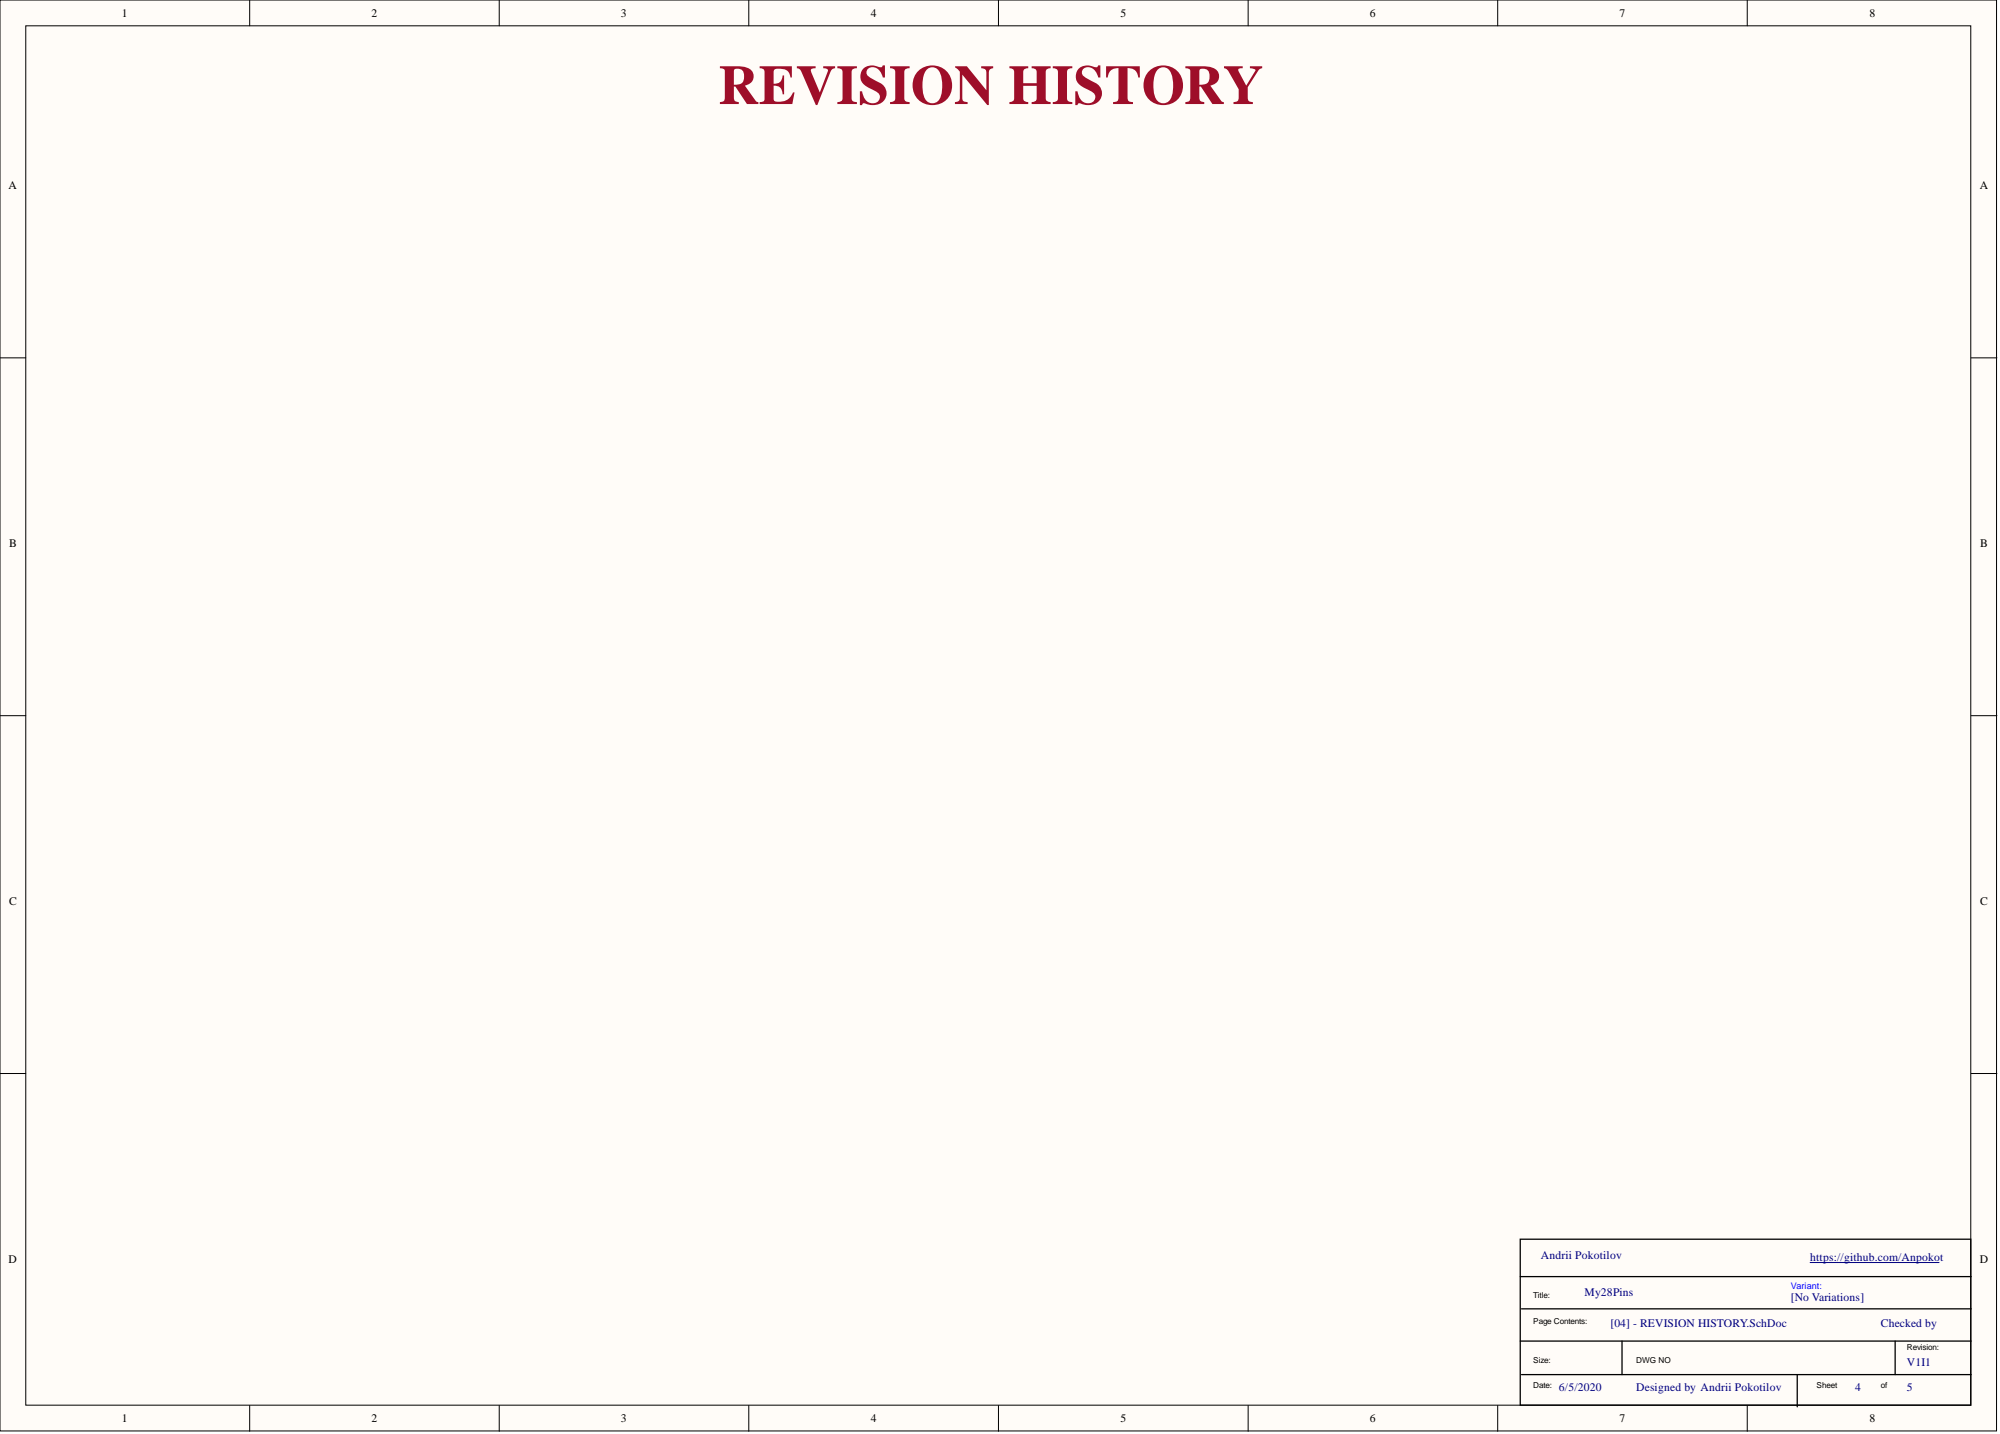
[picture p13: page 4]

https://github.com/Anpokot

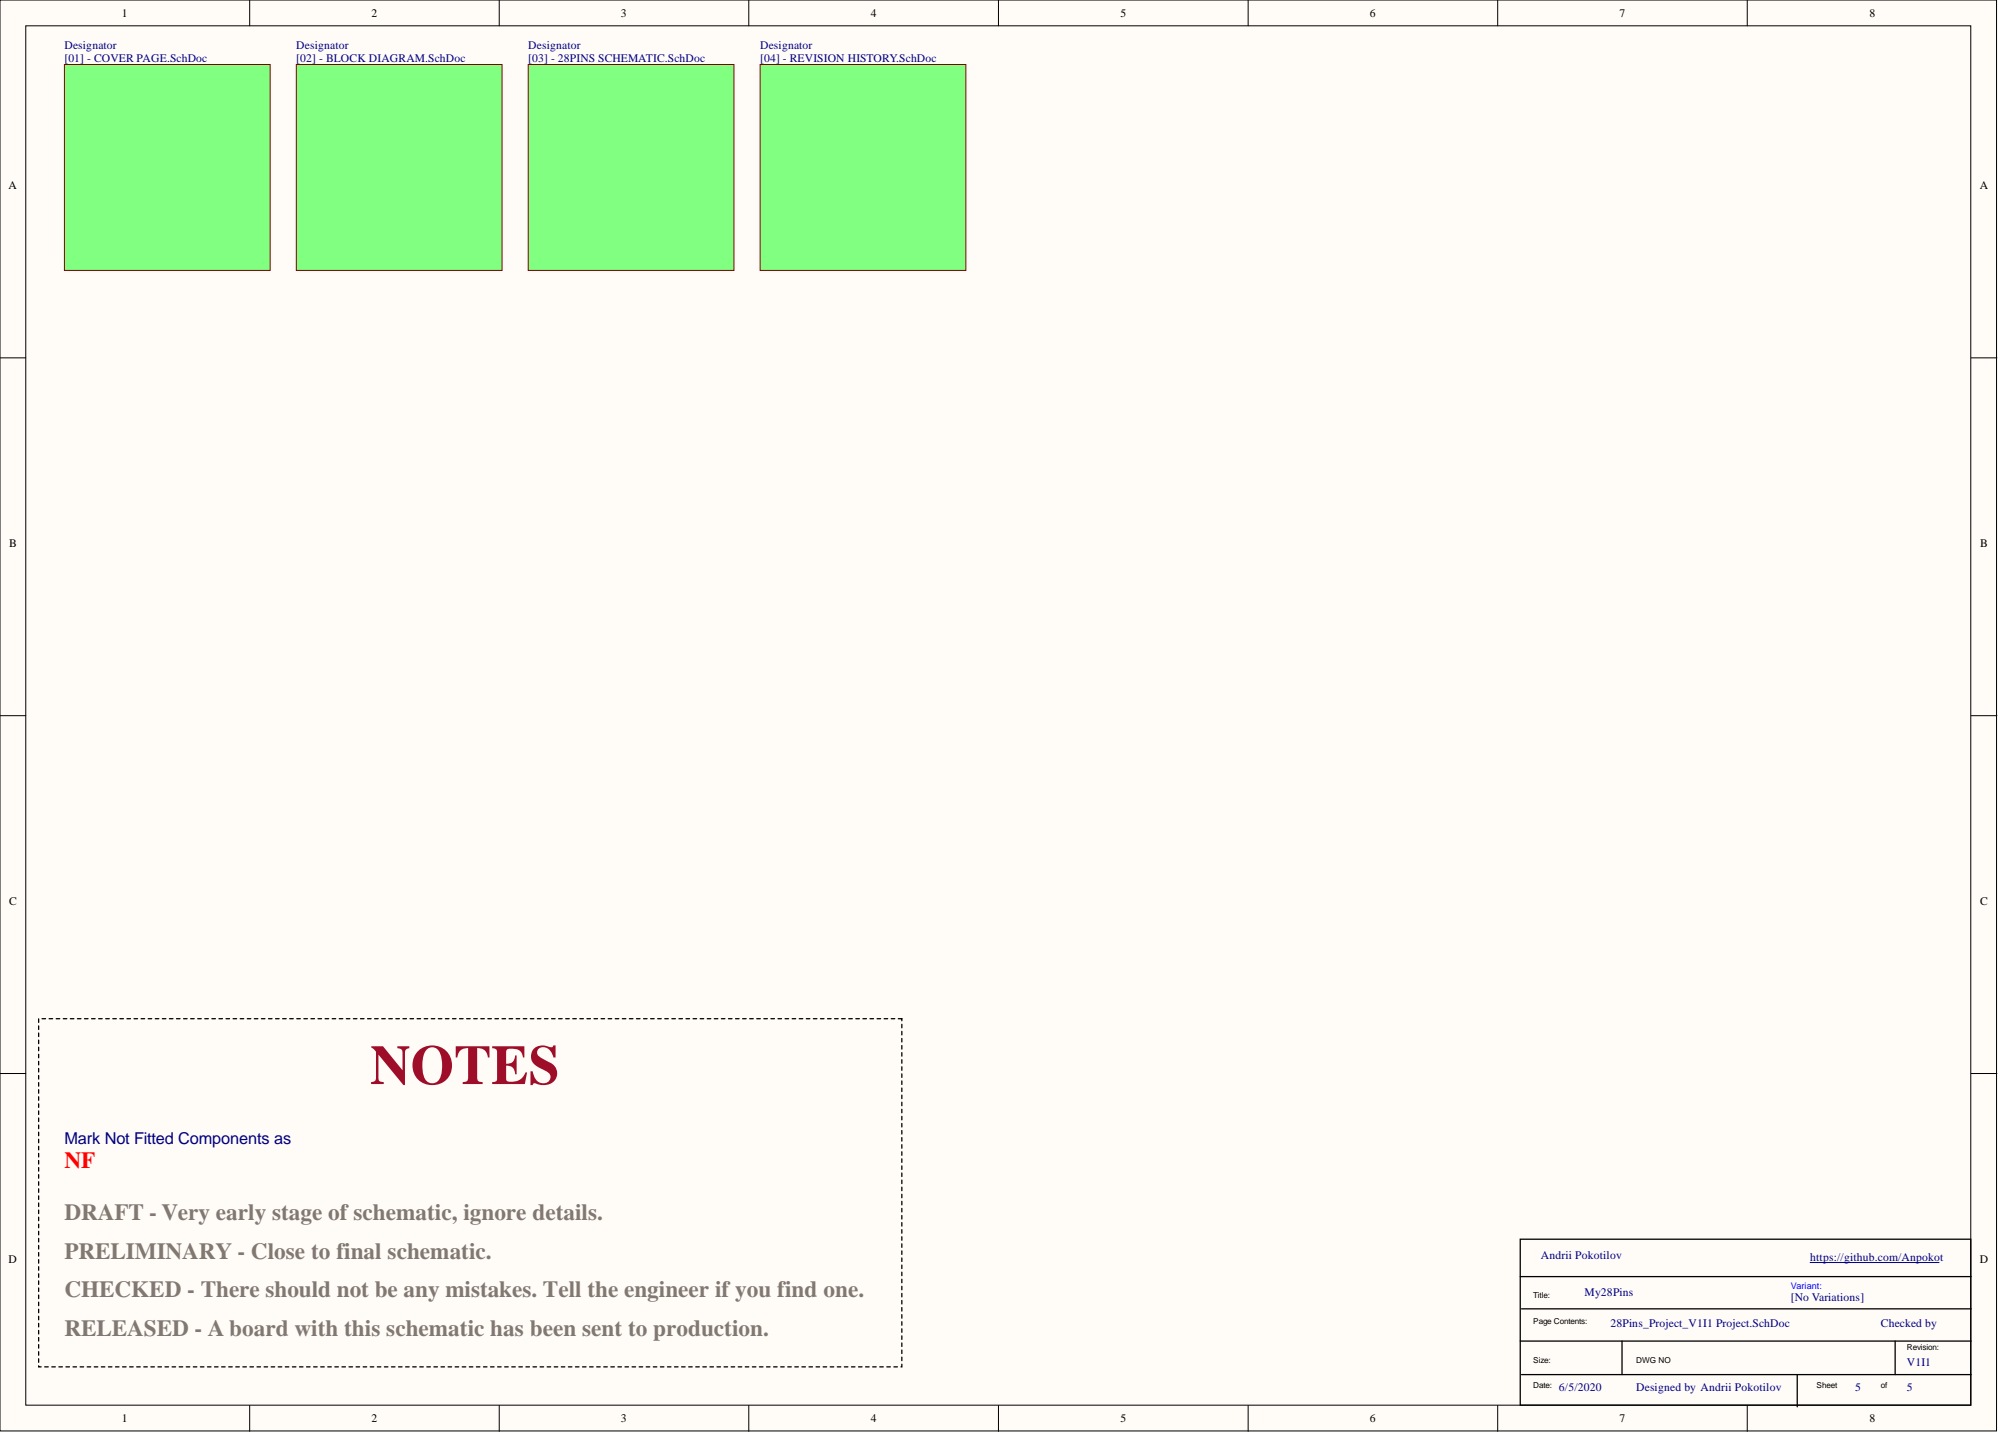
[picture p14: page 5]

Mark Not Fitted Components as

DRAFT - Very early stage of schematic, ignore details.
PRELIMINARY - Close to final schematic.
CHECKED - There should not be any mistakes. Tell the engineer if you find one.
RELEASED - A board with this schematic has been sent to production.

https://github.com/Anpokot

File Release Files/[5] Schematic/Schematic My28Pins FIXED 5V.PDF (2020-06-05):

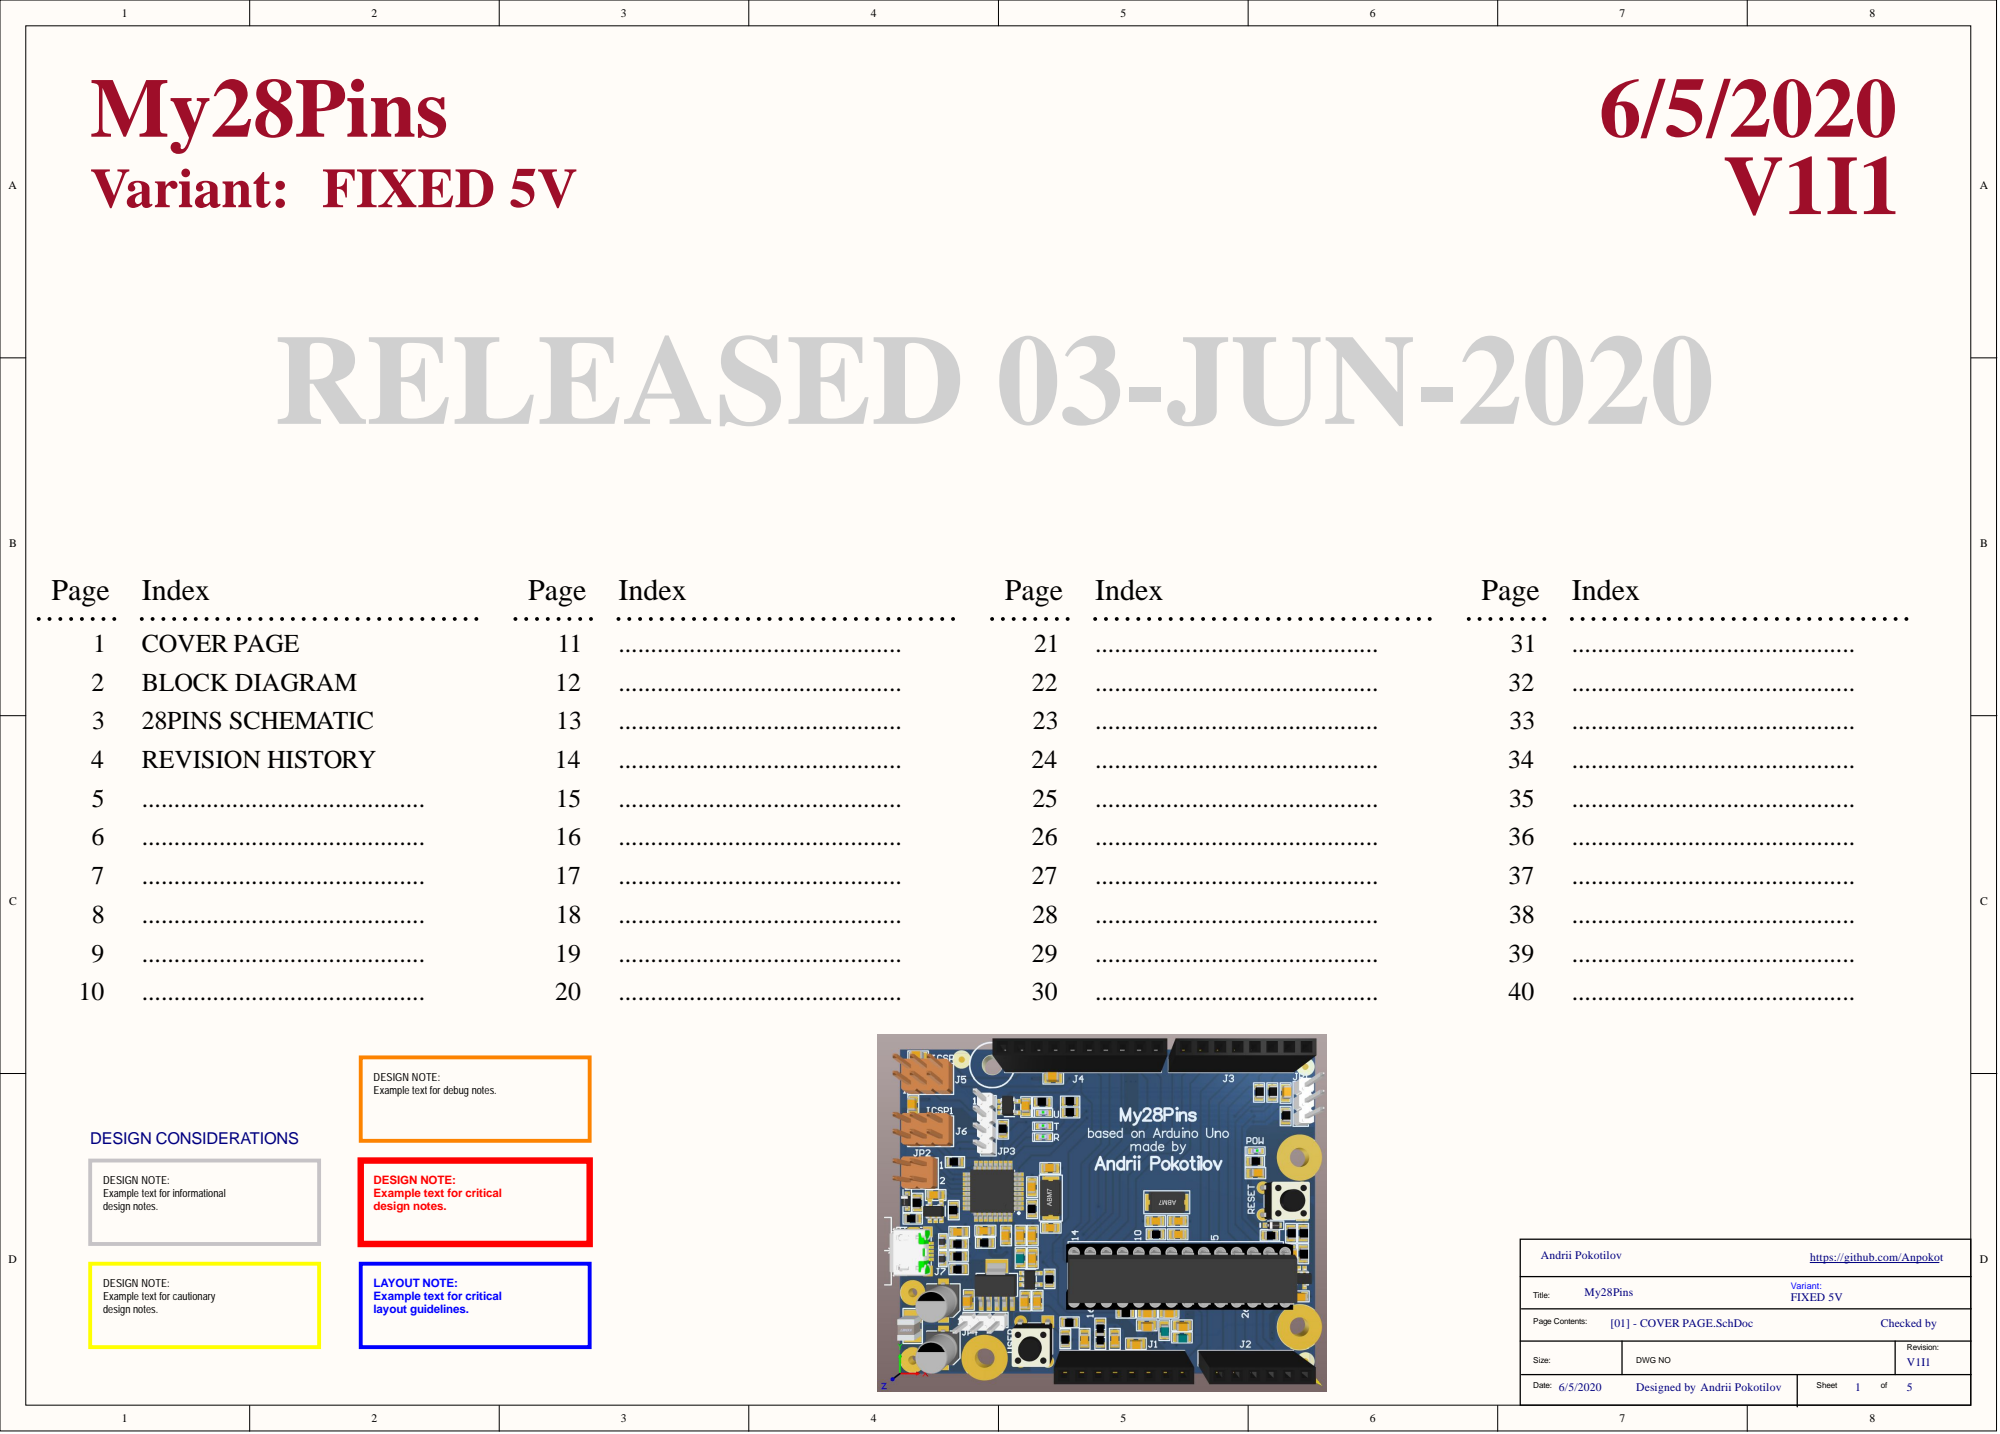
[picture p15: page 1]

DESIGN NOTE:
Example text for debug notes.

Example text for informational
design notes.

Example text for critical

https://github.com/Anpokot

Example text for cautionary

LAYOUT NOTE:
layout guidelines.

Size: | DWG NO | Revision: V1I1

Date: 6/5/2020 Designed by Andrii Pokotilov | Sheet of

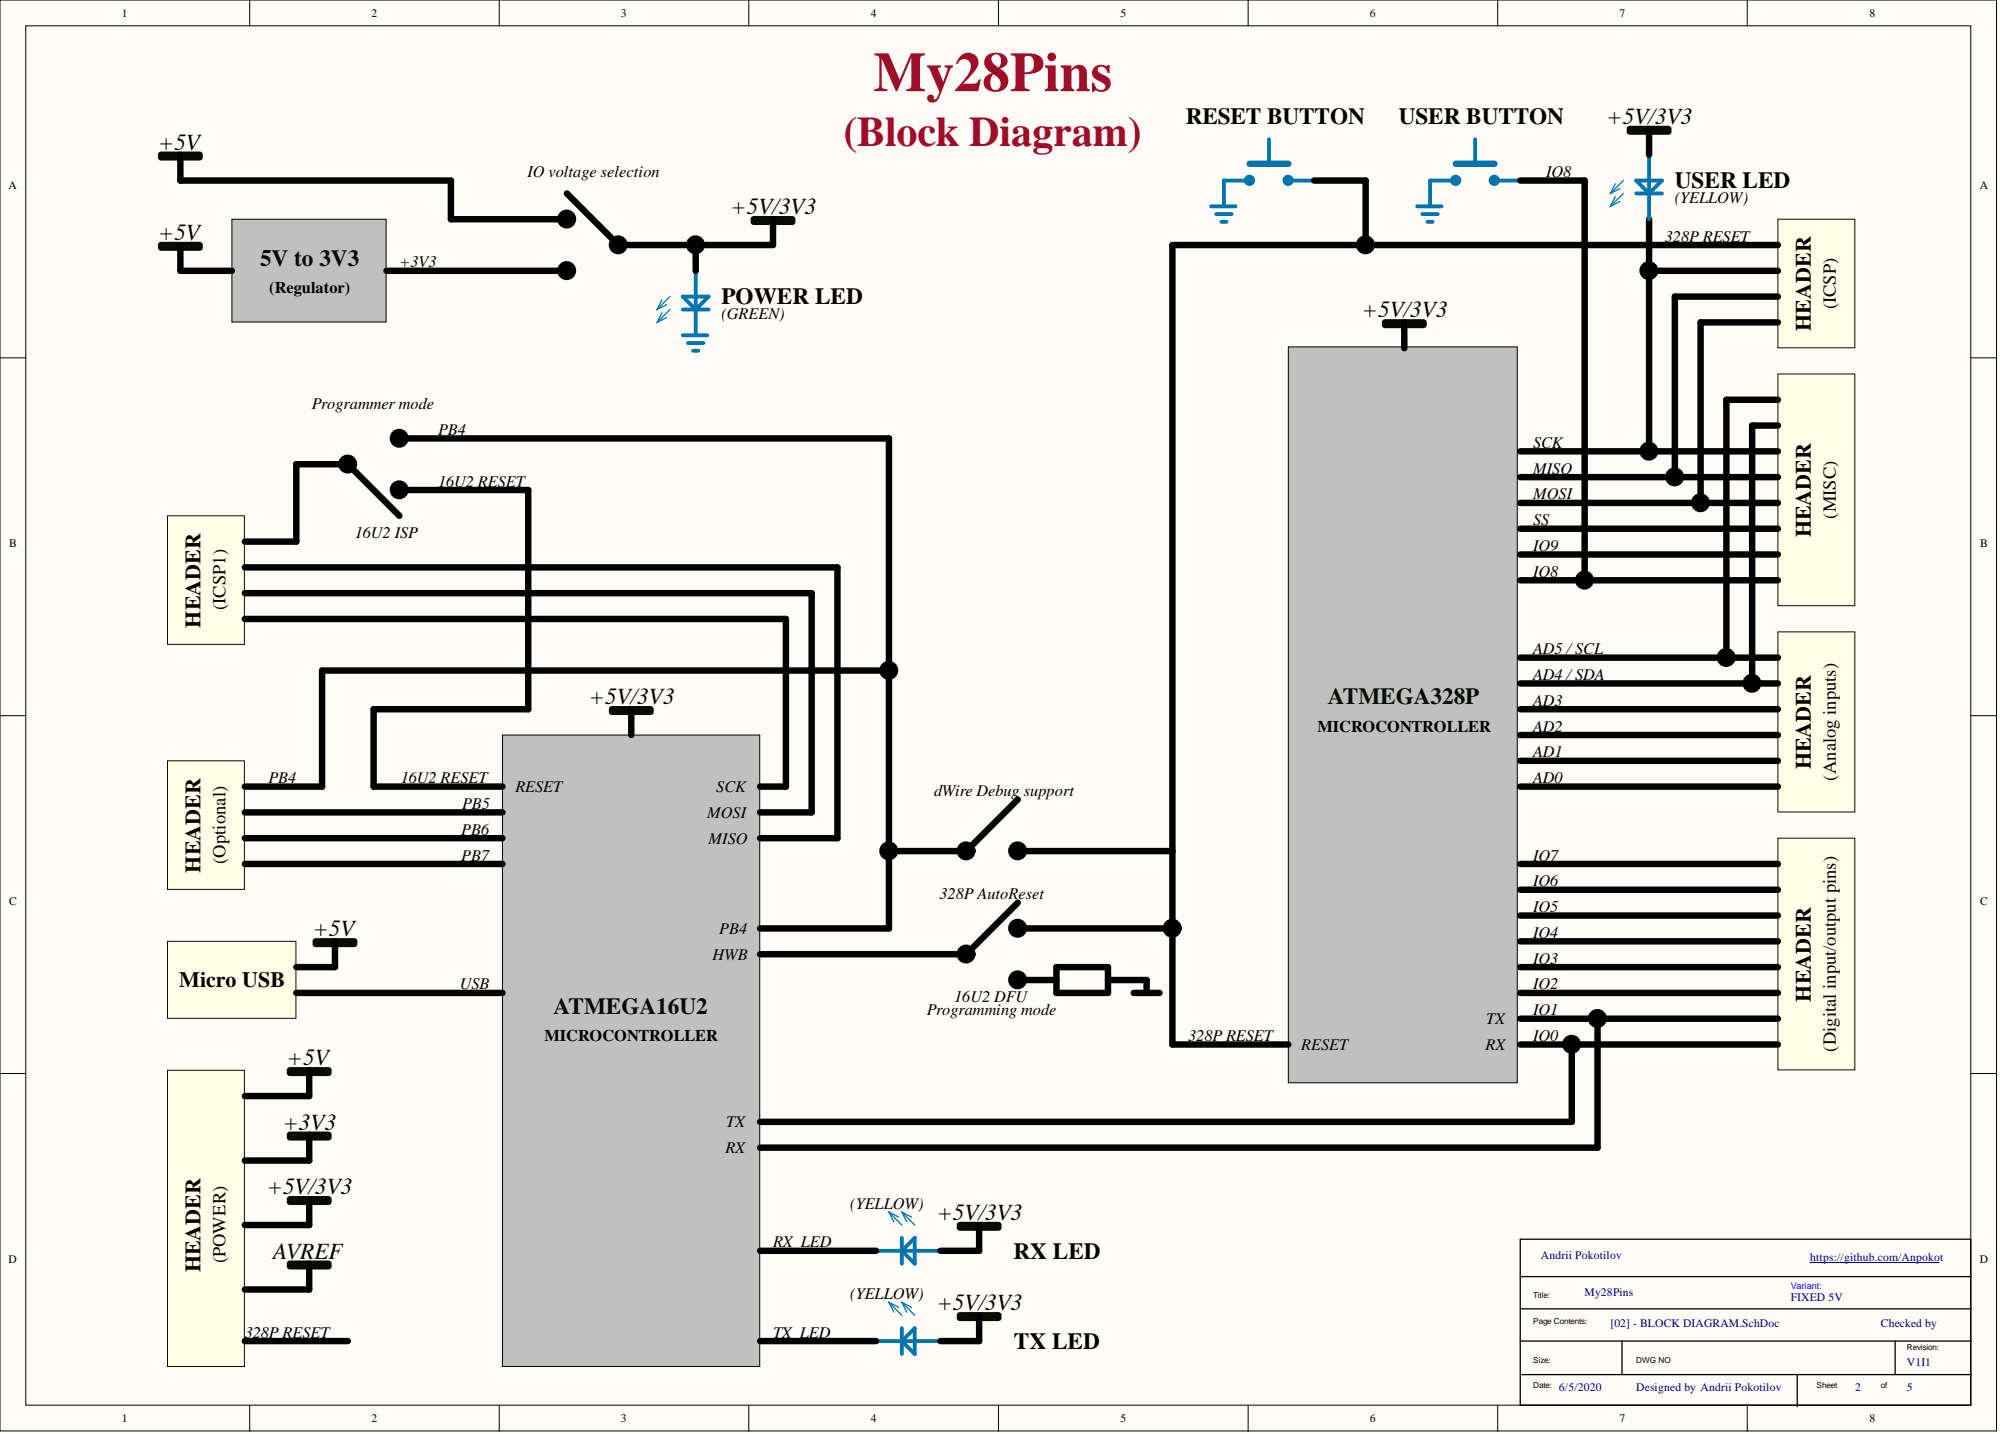
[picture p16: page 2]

MISO
MOSI
SS
IO9
IO8

AD5 / SCL
AD4 / SDA

https://github.com/Anpokot


DESIGN NOTE:
This board can be powered from micro USB
connector (J7) or a single +3.3V power rail
(through J1 pin 4). If +3.3V is used, fit R26 and
R28. In this case, JP4 & R27 must NOT be
fitted, otherwise the board may be damaged.

This board supports 5V or 3V3 voltage level on the IO pins:
1) 5V IO - Fit everything as defined in this schematic. NF means, do not fit this component.
2) 3.3V IO - Remove R27, Fit R28, *Replace Y1 (change from 16MHz to 10MHz), *Replace Y2 (change from 16MHz to
8MHz).
3) Both 5V and 3V3, selected through JP4 - Remove R27, Remove R28, Fit JP4, *Replace Y1 (change from 16MHz to
10MHz), *Replace Y2 (change from 16MHz to 8MHz).
*Note: The 16MHz crystals are not recommended for 3.3V operation. We need to adjust their values, thats why the
change.
IMPORTANT: Once you change the crystal value, you may need to re-compile your source code.

ORANGE 16U2_PB7 | | 100K

About JP3:
1) DebugWire support - Short 1&2. This was added to support possible debugWire debugging (programming?) of
328P through 16U2. In this case, the 16U2 needs to have a correct firmware and has to behave as a debugWire tool.
2) ISP programmer mode - Short 2&3. In this case, take a cable and connect J5 & J6 together. Upload AVRISP MKII
firmware into 16U2 and you can program 328P. Example of AVRISP MKII firmware can be found at LUFA projects:
http://www.fourwalledcubicle.com/LUFA.php (Tip: remap LEDs of the default AVRISP MKII LUFA project to the RX

Reset (PC1/dW) 24 | | 16U2_PB4 | | | J6

16U2_MISO
16U2_MOSI | | | 16U2_SCLK

+3V3_16U2_UCAP | UCAP 27 | | 16U2_SCLK_R

and TX LEDs on the 28Pin board)
3) ISP header - Short 3 & 4. In this mode, the ICSP1 header is used as a standard ISP header to program 16U2
through ISP interaface by an ISP programmer.

About JP1:
1) Autoreset Enabled - Short 1&2. In this case, 16U2 is used to reset 328P when firmware inside 328P is updated from
Arduino IDE.
2) 16U2 DFU mode Enabled - Short 2&3. 16U2 HWB pin is sampled by 16U2 during RESET. If pulled low, then after
Reset the 16U2 will go into DFU mode (it's the mode when you can flash 16U2 firmware through USB and Atmel Flip
software: http://www.atmel.com/tools/flip.aspx ).

16U2_TX_LED

AVCC 20 | MISO 22R

+AREF | AREF 21 | SS

PC6 (PCINT14/RESET) 1 | | IO8

AD5/SCL
AD4/SDA

AD2
AD1

PB7 (PCINT7/XTAL2/TOSC2) 10 | AD0

IO5
IO3 | | 1 1 2 2 3 3 4 4 5 5 6 6 7 7 8 8
IO4

Mounting holes 7.4mm pad 3.2mm drill
BOARD MOUNTING HOLES
ONE IN EACH CORNER
FIDUCIALS

IO2
IO1
IO0

LAYOUT NOTE:
1) Route all the POWER tracks with minimum track width 0.4mm.
2) Route all the other tracks by 0.4mm and change them by the end
of the design to 0.2mm. To change all of them at once, use this filter
"(not InNet('+*') and not InNet('GND')) and IsTrack and (OnLayer('L1')
or OnLayer ('L2'))" and then set 0.2mm width in PCB Inspector
panel.

https://github.com/Anpokot


https://github.com/Anpokot


Mark Not Fitted Components as

DRAFT - Very early stage of schematic, ignore details.
PRELIMINARY - Close to final schematic.
CHECKED - There should not be any mistakes. Tell the engineer if you find one.
RELEASED - A board with this schematic has been sent to production.

https://github.com/Anpokot







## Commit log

2020-06-05 Temlates updated
    [28Pin-Project-V1I1.PrjPcb, BOM Component Reference My28Pins 5V AND 3V3.xlsx, BOM Component Reference My28Pins FIXED 5V.xls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]
2020-06-05 Tiles updated
    [28Pins_Project_V1I1 Project.SchDoc]
2020-06-05 Tile updated
    [[01] - COVER PAGE.SchDoc, [02] - BLOCK DIAGRAM.SchDoc, [03] - 28PINS SCHEMATIC.SchDoc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]
